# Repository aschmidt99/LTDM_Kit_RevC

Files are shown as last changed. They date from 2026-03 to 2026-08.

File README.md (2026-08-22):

# LTDM Kit Rev C

Firmware and hardware assets for a Teensy 4.1 based LTDM (Lorentz Time-Domain Multiplex) kit.

### Programming
Iterate quickly on dsp and string behavior in `Code/LTDM_Kit/render.cpp`, leaving precise timing of sensing and actuating untouched by user.
### Interaction
Map hardware controls (buttons/sliders/pedals) to your algorithm through the UI layer.

## Project Structure

- `Code/LTDM_Kit`: Firmware running on Teensy 4.1
- `Code/Python`: capture, analysis, and Audacity automation scripts
- `Code/LTDM_Kit_Control.maxpat`: a maxpatch for overriding the LTDM Kit physical UI or running LTDM kit main board without UI.
- `Electronics`: KiCad project (schematic and pcb) for PCB design
- `CAD`: mechanical STEP/STL assets for enclosure

## Program and Upload
Firmware can be edited and uploaded to the teensy 4.1 via the Arduino 2.X IDE or from VS code.

### Arduino IDE
To use the Arduino IDE, you will need to [(install the Arduino IDE)](https://support.arduino.cc/hc/en-us/articles/360019833020-Download-and-install-Arduino-IDE). Once installed, download the Teensy Board library by following the instructions [(here)](https://www.pjrc.com/teensy/td_download.html).

After firmware changes are made, make sure the teensy is connected and seen by the dropdown menu in the upper left of the IDE. Use the 'upload' button next to this to flash new firmware.

### Arduino CLI (direct)
If this is your first time connecting from a new machine, run this one-time setup first:

1. Install Arduino CLI.
2. Add the Teensy board index URL.
3. Update board indexes and install the Teensy core.
4. Plug in Teensy 4.1 with a data-capable USB cable.
5. Verify the detected USB port before upload.

Example one-time setup commands:

```bash
# Add PJRC Teensy package index (safe to run again if already present)
arduino-cli config add board_manager.additional_urls https://www.pjrc.com/teensy/package_teensy_index.json

# Refresh indexes and install Teensy core
arduino-cli core update-index
arduino-cli core install teensy:avr

# Confirm Teensy core is installed
arduino-cli core list
```

Check that your Teensy is visible and note its port:

```bash
arduino-cli board list
```

On macOS, Teensy ports commonly look like `/dev/cu.usbmodem*`.

To flash code directly from terminal:

```bash
cd Code/LTDM_Kit
arduino-cli compile --fqbn teensy:avr:teensy41 .
arduino-cli upload --fqbn teensy:avr:teensy41 -p /dev/cu.usbmodemXXXX .
```

### VS Code tasks
To flash firmware from VS code, you can use the premade VS code tasks by using `Cmd+Shift+P` -> `Tasks: Run Task` and select:

- `Teensy: Compile LTDM_Kit`
- `Teensy: Upload LTDM_Kit (prompt port)`
- `Teensy: Upload LTDM_Kit (auto port)`
- `Teensy: Compile + Upload LTDM_Kit (auto port)`

Task definitions live in `.vscode/tasks.json`.

## How the Firmware is Organized

### Essential core files (base firmware)

- `LTDM_Kit.ino`: startup order and top-level loop (`setup()` and `loop()`).
- `flexpwm.cpp` / `flexpwm.h`: hardware timing, ISR, ADC reads, and PWM update path.
- `render.cpp` / `render.h`: per-sample behavior, where algorithm/control logic is authored.
- `ui.cpp` / `ui.h`: physical control scan (buttons/sliders/pedals), LED updates, and serial telemetry printout.
- `channel.h`: per-channel runtime/state struct fields used by ISR and render.
- `context.h`: shared frame context passed into `render()` each sample.
- `pinmap.h`: board pin assignments and hardware routing constants.
- `system_config.h`: global compile-time configuration (sample rate, buffer sizes, PWM resolution).

### Optional or bonus helper modules

These are useful, but not strictly required for a minimal "sense -> render -> actuate" base path.

- `serialctrl.cpp` / `serialctrl.h`: optional host serial override of hardware UI state (used by Max patch control).
- `capture_stream.cpp` / `capture_stream.h`: optional deterministic capture trigger and streaming for measurement scripts.
- `harmonics.cpp` / `harmonics.h`: additive harmonic oscillator bank and zero-crossing pitch tracking.
- `visualAlias.cpp` / `visualAlias.h`: optional visual alias output behavior by plugging a 12V LED strip into one of the channels.
- `SineTable.cpp` / `SineTable.h`: lookup-table sine source used by harmonic/visual helper DSP.
- `debug.h`: compile-time debug print macros (`DEBUG_PRINT`, `DEBUG_PRINTLN`).

At runtime, the flow is:

1. ISR acquires channel state and UI state into `context`.
2. `render(context)` computes output values once per sample.
3. PWM/sense outputs are driven from those computed values.

## Codebase division-of-labor

This codebase intentionally separates three concerns:

1. Real-time infrastructure: sample timing, GPIO/PWM scheduling, ADC/sense capture.
2. Control surface: what knobs/buttons/pedals currently mean.
3. Algorithm: how measured input becomes actuation output.

The design goal is to let you iterate and develop actuation and feedback behavior without destabilizing anything with critical timing, such as the regular periodic sense + actuate loop.

In practice, treat `render.cpp` as your sandbox for algorithmic ideas:

- Feedback shaping
- Noise injection and excitation strategies
- RMS/energy targeting
- Harmonic synthesis
- Cross-channel coupling experiments

## Where to Make Changes

### Audio/actuation behavior

Edit `Code/LTDM_Kit/render.cpp`.

Key entry points:

- `bool renderSetup(LorentzContext *context)` for one-time setup
- `void render(LorentzContext *context)` for per-sample behavior

Useful signals available from `context`:

- `context->ch[0].in`, `context->ch[1].in` (channel's sensed audio input)
- `context->buttons[0]` (button 0-7 are the latching buttons, and 6-15 are the momentary push buttons)
- `context->sliders[0..15]` (slider 0-7 are the potentiometers, 8-15 are the sliders)
- `context->pedals[0..1]` (optionally connect up to 2 expression pedals)

### Button/slider behavior mapping

Edit `Code/LTDM_Kit/ui.cpp` and `Code/LTDM_Kit/render.cpp` together.

How it works:

1. `ui.cpp` scans physical mux inputs and sets UI LED outputs.
2. `render.cpp` assigns meaning to those logical indices.

### Pin assignments

Edit `Code/LTDM_Kit/pinmap.h` only if attaching additional functions to the available GPIOs.

### Render/control behavior (channel 1 focused)

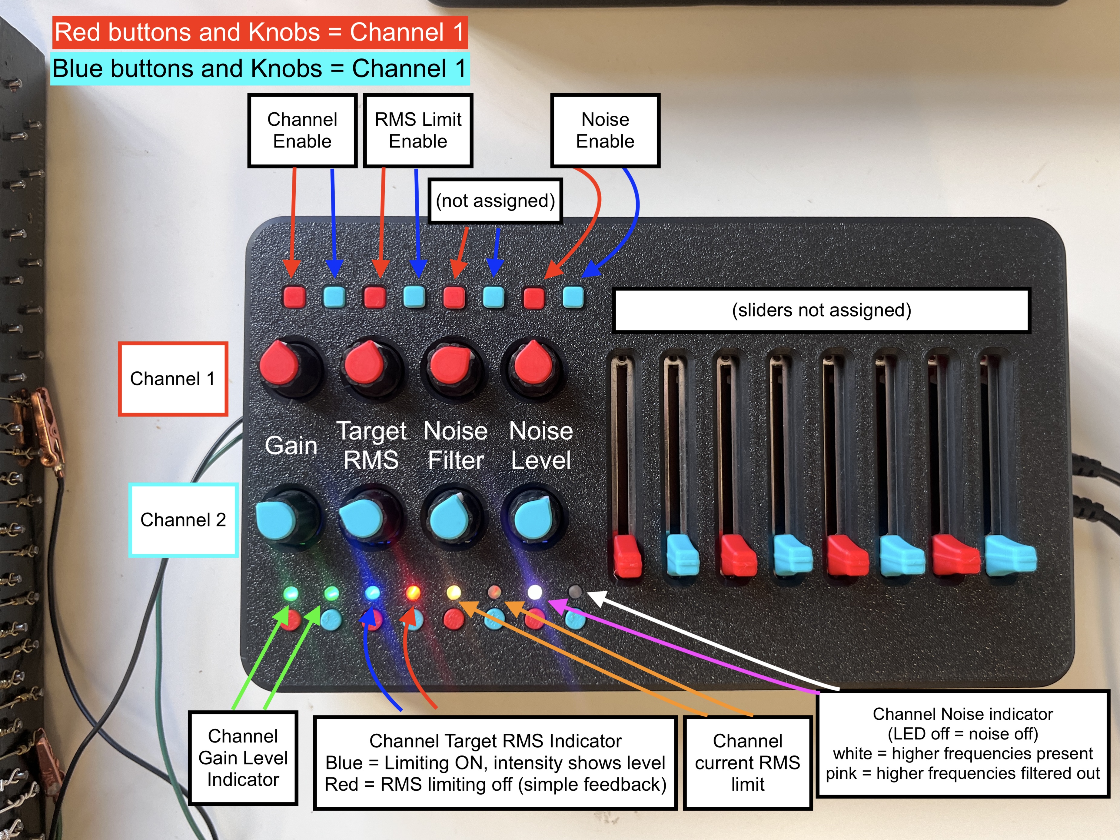
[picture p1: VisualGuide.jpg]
VisualGuide


In `Code/LTDM_Kit/render.cpp`:

- Button 0/1 enables channel 1 and 2 output respectively (`enablePin` high/low).
- Button 2 toggles RMS-targeted gain behavior for CH1.
- Button 6 gates CH1 noise injection.
- Button 8 requests capture start while capture is armed.

- Slider 0: CH1 feedback gain (`fbGain`).
- Slider 1: CH1 target RMS.
- Slider 2: noise update rate (acts like coarse smoothing on random term).
- Slider 3: CH1 noise scale.
- Slider 4: harmonic frequency smoothing parameter (`alpha`).
- Sliders 8..15: gains for harmonics 1..8 (`NUM_HARMONICS = 8`).

- Note: Channel 2 currently carries visual-alias pulse output behavior (`renderLEDPulse(...)`) rather than string feedback behavior

### LED/UI feedback

In `Code/LTDM_Kit/ui.cpp`:

- TLC5947 LEDs reflect enable/limit/target and measured RMS states.
- UI scan runs in two-step mux read/write cycles.
- `output()` also prints debug telemetry over serial every ~100 ms (as long as the the python audio capture stream is idle.)

### Serial override mode

`Code/LTDM_Kit/serialctrl.cpp` can override hardware controls via framed serial packets. There is an example max/msp patch ('LTDM_Kit_Control.maxpat') that already has this setup.

- Start marker: `255`
- End marker: `254`
- Payload: mode + 16 sliders + 16 buttons + 2 pedals (34 bytes)

When override is active, incoming values are written directly into the shared UI state arrays.

## Python Tools

The Python tools in `Code/Python` are used for measurement, capture automation, and analysis around the firmware:

- `capture_teensy_plus_interface.py`: Capture audio directly from Teensy (what the teensy 'hears' from the EMF sensing circuitry) and 2 channels of audio from a connected audio interface. Optionally import these files directly to audacity.
- `run_trial.py`: Prompt for trial/profile/duration and launch the capture workflow via named profiles.
- `capture_teensy_stream.py`: Capture Teensy stream only (without interface capture), with optional WAV export.
- `rigol_capture.py`: Run Rigol DS1054Z waveform/screenshot capture and write trial metadata.
- `load_rigol_capture.py`: Load and interactively inspect saved Rigol capture files.
- `rigol_screen.py`: Capture or convert Rigol's screen images.
- `plot_teensy_stream.py`: Plot saved Teensy stream files for quick signal inspection.

If you are starting from scratch, run this script first:

- `Code/Python/run_trial.py`

It prompts for trial and duration, auto-suggests the next trial number, and launches the full capture pipeline with known-good defaults.

Full Python docs:

- `Code/Python/PYTHON_README.md`

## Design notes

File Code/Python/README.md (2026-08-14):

# LTDM Python Scripts
# warning: I vibe-coded the hell out of this shit big time.

This folder contains two main workflows:

- LTDM Teensy + audio-interface capture, with optional Audacity timeline automation.
- Rigol DS1054Z waveform/screenshot capture and review.

## Folder Highlights

- `capture_teensy_plus_interface.py`: primary capture pipeline (Teensy + interface + Audacity import).
- `run_capture_trial_prompt.py`: interactive launcher that prompts trial and duration.
- `capture_teensy_stream.py`: Teensy-only binary/WAV capture.
- `legacy/capture_teensy_to_audacity.py`: older Teensy + Audacity flow (kept for reference/troubleshooting).
- `rigol_capture.py`: full 4-channel DS1054Z RAW capture to HDF5 + PNG + metadata.
- `load_rigol_capture.py`: browse and plot saved Rigol captures.
- `rigol_screen.py`: capture scope screen PNG or convert saved raw screen bytes.
- `plot_teensy_stream.py`: quick matplotlib plot of Teensy `.bin` streams.
- `rigol_common.py`: shared Rigol constants/helpers/plot logic.
- `legacy/test.py`: utility script for inspecting raw Rigol screen `.bin` files.

## Workflow Diagram

```mermaid
flowchart TD
  T[VS Code Task:\nPython Capture Teensy+Interface] --> P[run_capture_trial_prompt.py]
  P --> CPI[capture_teensy_plus_interface.py]
  CPI --> TS[(Teensy Serial Stream)]
  CPI --> IF[(Audio Interface Capture)]
  CPI --> AU[(Audacity import/update optional)]
  CPI --> EXP[(experiments/ output)]

  U1[Manual run] --> CTS[capture_teensy_stream.py]
  CTS --> EXP

  U2[Manual run] --> RIG[rigol_capture.py]
  RIG --> RC[rigol_common.py]
  RIG --> RS[rigol_screen.py]
  RIG --> EXP

  U3[Manual run] --> LRC[load_rigol_capture.py]
  LRC --> RC
  LRC --> EXP

  LEG[legacy/] --> LTA[legacy/capture_teensy_to_audacity.py]
  LEG --> TST[legacy/test.py]
```

## Requirements

Use Python 3.10+ recommended.

Install core dependencies:

```bash
python3 -m pip install pyserial numpy sounddevice soundfile matplotlib h5py ds1054z python-vxi11 pillow questionary
```

Notes:
- On macOS, `sounddevice` requires microphone permissions for terminal/VS Code.
- Audacity automation requires mod-script-pipe enabled and Audacity running.

## Recommended Daily Workflow (LTDM Capture)

### Option A: VS Code task (recommended)

Run task:

- `Python: Capture Teensy+Interface (prompt trial/duration)`

This task runs `run_capture_trial_prompt.py`, which:

- Suggests next trial number from `experiments/TeensyCapture/audacity_timeline_state.json`.
- Lets you override trial (including rerun of an existing trial).
- Prompts duration in seconds.
- Launches `capture_teensy_plus_interface.py` with project defaults.

### Option B: direct command

```bash
cd Code/Python
python3 capture_teensy_plus_interface.py \
  --port /dev/cu.usbmodem199934501 \
  --trial 7 \
  --duration 3 \
  --iface-device 6 \
  --iface-sample-rate 192000 \
  --iface-channels 2 \
  --iface-start-mode arm-gated \
  --iface-pre-roll 0.05 \
  --iface-post-roll 0.05 \
  --iface-trim-to-teensy \
  --iface-auto-align \
  --audacity-import \
  --audacity-command-spacing 0.25 \
  --audacity-reset-passes 3 \
  --audacity-pre-import-delay 0.10 \
  --audacity-post-import-delay 0.10
```

## Script Reference

## 1) `capture_teensy_plus_interface.py`

Primary synchronized capture script.

What it does:
- Arms Teensy and captures serial stream (2ch, 20 kHz).
- Captures interface audio (multi-channel, typically 2ch at 192 kHz).
- Optionally auto-aligns interface to Teensy via envelope correlation.
- Optionally trims interface exactly to Teensy duration.
- Writes per-trial WAVs + metadata JSON.
- Optionally imports/appends clips to 4 fixed Audacity tracks.

Key outputs per trial:
- `teensy_stream.bin`
- `teensy_stream_Ch1.wav`
- `teensy_stream_ch2.wav`
- `interface_capture_ch1.wav`
- `interface_capture_ch2.wav`
- `teensy_interface_capture_metadata.json`

Useful flags:
- `--iface-list-devices`
- `--iface-start-mode marker|arm|arm-gated`
- `--iface-auto-align` / `--iface-no-auto-align`
- `--iface-trim-to-teensy` / `--iface-no-trim-to-teensy`
- `--audacity-import` / `--no-audacity-import`
- `--audacity-reset-timeline`

## 2) `run_capture_trial_prompt.py`

Interactive launcher for the main capture script.

What it does:
- Reads prior timeline state.
- Proposes auto-incremented trial.
- Prompts trial + duration in terminal.
- Runs the full capture command with known-good defaults.

Run:

```bash
cd Code/Python
python3 run_capture_trial_prompt.py
```

## 3) `capture_teensy_stream.py`

Teensy-only capture utility.

What it does:
- Arms Teensy and waits for capture marker.
- Captures binary stream for requested duration.
- Saves raw channel splits and optional WAVs.

Run example:

```bash
cd Code/Python
python3 capture_teensy_stream.py \
  --port /dev/cu.usbmodem199934501 \
  --trial 1 \
  --duration 5 \
  --save-wav
```

## 4) `legacy/capture_teensy_to_audacity.py`

Legacy Audacity automation script.

Use this mainly for regression/troubleshooting versus the newer pipeline.

Run example:

```bash
cd Code/Python
python3 legacy/capture_teensy_to_audacity.py --port /dev/cu.usbmodem199934501
```

## 5) `plot_teensy_stream.py`

Quick waveform viewer for Teensy `.bin` captures.

Run example:

```bash
cd Code/Python
python3 plot_teensy_stream.py experiments/TeensyCapture/trial_1/teensy_stream.bin --duration 1.0 --channel 1
```

## 6) `rigol_capture.py`

Interactive DS1054Z RAW waveform capture.

What it does:
- Connects to Rigol via LAN/VXI-11 using `SCOPE_IP` from `rigol_common.py`.
- Captures scope screen.
- Stops scope if needed.
- Reads 6M-point RAW data for all 4 channels.
- Saves HDF5 + trial metadata + rendered PNG.

Run:

```bash
cd Code/Python
python3 rigol_capture.py
```

## 7) `load_rigol_capture.py`

Interactive loader/viewer for prior Rigol captures.

Run:

```bash
cd Code/Python
python3 load_rigol_capture.py
```

## 8) `rigol_screen.py`

Screen capture/conversion helper.

Live capture:

```bash
cd Code/Python
python3 rigol_screen.py --ip 169.254.123.183 --out rigol_screen.png
```

Convert existing raw screen file:

```bash
cd Code/Python
python3 rigol_screen.py --bin 20260811_rigol_screen.bin
```

## 9) `rigol_common.py`

Shared module used by Rigol scripts.

Contains:
- `SCOPE_IP`
- Channel mappings/colors
- RAW count to voltage conversion
- Scope-style plotting + zoom/decimation behavior

## 10) `legacy/test.py`

Small diagnostic utility for raw scope screen bytes.

Use when debugging corrupted/partial `.bin` screen captures.

Run:

```bash
cd Code/Python
python3 legacy/test.py
```

## Data Layout

Typical output tree:

```text
Code/Python/experiments/
  TeensyCapture/
    audacity_timeline_state.json
    trial_1/
    trial_2/
  <RigolExperimentName>/
    experiment.json
    trial_1/
      rigol_capture.h5
      rigol_capture.png
      rigol_screen.png
      trial_metadata.json
```

## Troubleshooting

Audacity import does not work:
- Confirm Audacity is open.
- Confirm mod-script-pipe is enabled.
- Confirm pipe files exist at `/tmp/audacity_script_pipe.to.<uid>` and `/tmp/audacity_script_pipe.from.<uid>`.

No interface input:
- Run `capture_teensy_plus_interface.py --iface-list-devices`.
- Verify `--iface-device` index/name.
- Check macOS microphone permissions.

Rigol connection fails:
- Verify scope IP in `rigol_common.py`.
- Confirm LAN link and that scope responds on VXI-11.

## Quick Sanity Checks

Compile scripts:

```bash
cd Code/Python
python3 -m py_compile capture_teensy_plus_interface.py run_capture_trial_prompt.py
```

Run one prompted trial:

```bash
cd Code/Python
python3 run_capture_trial_prompt.py
```

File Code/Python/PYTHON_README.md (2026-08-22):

# LTDM Python Scripts
## Warning: I vibe-coded the hell out of this shit big time.
This folder contains two main workflows:

- LTDM Teensy + audio-interface capture, with optional Audacity timeline automation.
- Rigol DS1054Z data capture and review.

## Quick Start

Run an interactive trial:

```bash
cd Code/Python
python3 run_trial.py
```

Run a non-interactive trial:

```bash
cd Code/Python
python3 run_trial.py --experiment TeensyCapture --trial 1 --profile teensy_interface_no_audacity --duration 5
```

Run Teensy-only capture:

```bash
cd Code/Python
python3 -m capture.teensy_stream --port /dev/cu.usbmodem199934501 --trial 1 --duration 5 --save-wav
```

## Folder Map

- `capture/`: Teensy and interface capture implementations.
- `rigol/`: Rigol capture, scope screen, and shared Rigol plotting helpers.
- `core/`: Shared path, profile, and metadata normalisation helpers.
- `analysis/`: Post-capture plotting/inspection tools.
- `docs/`: Python-side technical schema/reference docs.
- `run_trial.py` remains the top-level interactive launcher.

## Metadata Schema

Schema design is fixed in:

- `docs/trial_metadata_schema_v2.md`

This schema is the canonical contract for trial metadata before true acquisition begins.
It defines:

- Required versus optional fields.
- Authority precedence (firmware > measured properties > Python defaults).
- Trial failure semantics.
- Relative-path policy.
- Audacity lifecycle event recording.
- Assignment map policy (including explicit `N/A` for unassigned controls).
- Required FlexPWM TDM timing metadata using meaningful labels (for example sample period, main sense pulse end, alt sense pulse start/end, actuation pulse start) with time and duty-cycle values.

Telemetry integration reads firmware `@TLM1` arm snapshots before capture marker bytes and stores the payload in trial metadata.

Ingestion/persistence writes canonical schema metadata to:

- `trials/trial_####/trial_metadata_v2.json`

Capture scripts still write their existing operational metadata files, but canonical firmware authority, FlexPWM timing, controls, stream status, and relative-path file manifests now live in `trial_metadata_v2.json`.
Operational metadata includes a `schema_v2_path` pointer so downstream tooling can resolve the canonical record directly.

Audacity lifecycle automation records concise `lifecycle_events` with UTC timestamps (launch/open-or-create/import/save/close/error) and persists Audacity status into both operational metadata and schema-v2 metadata.
For each experiment, automation uses `orchestration/<experiment_name>.aup3`: it opens this project when needed, or creates it on first save without issuing an explicit Audacity New command.
Follow-up trials default to append mode and skip explicit project reopening to avoid "already open in another window" errors; rebuild mode is only forced when track count is successfully queried and is below the required base tracks.
If Audacity is not running, automation fails fast with a recorded lifecycle error rather than hanging on script-pipe open.
To reduce post-import/save instability, additional padding is available with `--audacity-pre-save-delay` and `--audacity-post-save-delay`.
When using `run_trial.py`, these delay flags are forwarded automatically to `capture.teensy_plus_interface`.

Repository hygiene and workflow stability includes two safeguards:

- `run_trial.py` resolves script/output paths from its own file location, so it behaves consistently regardless of current working directory.
- `.gitignore` excludes generated artefacts (`.DS_Store`, `__pycache__`, `.pyc`, trial outputs, and local Audacity project sidecars).

## Folder Highlights

- `capture/teensy_plus_interface.py`: primary capture pipeline (Teensy + interface + Audacity import).
- `run_trial.py`: interactive trial runner using named capture profiles.
- `capture/teensy_stream.py`: Teensy-only binary/WAV capture.
- `rigol/capture.py`: full 4-channel DS1054Z RAW capture to HDF5 + PNG + metadata.
- `rigol/load_capture.py`: browse and plot saved Rigol captures.
- `core/experiment_profile.py`: shared experiment-level metadata loader/prompt/save helper.
- `rigol/screen.py`: capture scope screen PNG or convert saved raw screen bytes.
- `analysis/plot_teensy_stream.py`: quick matplotlib plot of Teensy `.bin` streams.
- `rigol/common.py`: shared Rigol constants/helpers/plot logic.

## Workflow Diagram

```mermaid
flowchart TD
  T[VS Code Task:\nPython Capture Teensy+Interface] --> P[run_trial.py]
  P --> CPI[capture.teensy_plus_interface]
  CPI --> TS[(Teensy Serial Stream)]
  CPI --> IF[(Audio Interface Capture)]
  CPI --> AU[(Audacity import/update optional)]
  CPI --> EXP[(experiments/ output)]

  U1[Manual run] --> CTS[capture.teensy_stream]
  CTS --> EXP

  U2[Manual run] --> RIG[rigol.capture]
  RIG --> RC[rigol.common]
  RIG --> RS[rigol.screen]
  RIG --> EXP

  U3[Manual run] --> LRC[rigol.load_capture]
  LRC --> RC
  LRC --> EXP
```

## Requirements

Use Python 3.10+ recommended.

Install core dependencies:

```bash
python3 -m pip install pyserial numpy sounddevice soundfile matplotlib h5py ds1054z python-vxi11 pillow questionary
```

Notes:
- On macOS, `sounddevice` requires microphone permissions for terminal/VS Code.
- Audacity automation requires mod-script-pipe enabled and Audacity running.

### macOS Apple Silicon note (important)

If you see an error like "incompatible architecture (have 'x86_64', need 'arm64')" when importing `matplotlib`, you are launching the script with the wrong Python interpreter.

For this repo, use the project virtual environment interpreter directly:

```bash
cd Code/Python
../../.venv/bin/python -m rigol.capture
```

If needed, reinstall the plotting stack into that same interpreter:

```bash
../../.venv/bin/python -m pip install --upgrade --force-reinstall matplotlib numpy
```

## Recommended Daily Workflow (LTDM Capture)

### Option A: VS Code task (recommended)

Run task:

- `Python: Capture Teensy+Interface (prompt trial/duration)`

This task runs `run_trial.py`, which:

- Prompts experiment name (default `TeensyCapture`) when not passed by flag.
- Suggests next trial number from `experiments/TeensyCapture/orchestration/audacity_timeline_state.json` (with folder fallback).
- Lets you override trial (including rerun of an existing trial).
- Prompts for one profile: `interface_audacity`, `interface_no_audacity`, `teensy_interface_audacity`, `teensy_interface_no_audacity`, `rigol_only`, `full_stack_audacity`, or `full_stack_no_audacity`.
- Uses duration from `orchestration/experiment_profile.json` (`duration_seconds`) for non-`rigol_only` profiles.
- Accepts `--duration` as an override for a specific run.
- For trial 2+, shows “Change user-reported variable?” with an arrow-navigable field list (current values shown) and saves any edits before capture.
- Prompts once for experiment metadata if `orchestration/experiment_profile.json` does not yet exist.
- Launches `capture.teensy_plus_interface` with project defaults.

### Capture Profiles

- `interface_audacity`: Interface recording only, with Audacity import.
- `interface_no_audacity`: Interface recording only, without Audacity import.
- `rigol_only`: Rigol capture only for the selected experiment/trial.
- `teensy_interface_audacity`: Teensy + interface recording, with Audacity import.
- `teensy_interface_no_audacity`: Teensy + interface recording, without Audacity import.
- `full_stack_audacity`: Teensy + interface + Audacity + Rigol.
- `full_stack_no_audacity`: Teensy + interface + Rigol, without Audacity import.

### Option B: direct command

```bash
cd Code/Python
python3 -m capture.teensy_plus_interface \
  --port /dev/cu.usbmodem199934501 \
  --trial 7 \
  --duration 3 \
  --iface-device 6 \
  --iface-sample-rate 192000 \
  --iface-channels 2 \
  --iface-start-mode arm-gated \
  --iface-pre-roll 0.05 \
  --iface-post-roll 0.05 \
  --iface-trim-to-teensy \
  --iface-auto-align \
  --audacity-import \
  --audacity-command-spacing 0.25 \
  --audacity-reset-passes 3 \
  --audacity-pre-import-delay 0.10 \
  --audacity-post-import-delay 0.10
```

Audio + Rigol in one run:

```bash
cd Code/Python
python3 -m capture.teensy_plus_interface \
  --port /dev/cu.usbmodem199934501 \
  --trial 7 \
  --duration 3 \
  --iface-device 6 \
  --iface-sample-rate 192000 \
  --iface-channels 2 \
  --iface-start-mode arm-gated \
  --iface-pre-roll 0.05 \
  --iface-post-roll 0.05 \
  --iface-trim-to-teensy \
  --iface-auto-align \
  --audacity-import \
  --post-rigol
```

## Script Reference

1. `run_trial.py`
Purpose: interactive daily launcher (experiment/trial/profile prompts, duration defaults, metadata edits for follow-up trials).
Run:

```bash
cd Code/Python
python3 run_trial.py
```

2. `capture/teensy_plus_interface.py`
Purpose: main synchronized capture path (Teensy + interface + optional Audacity + optional post-Rigol).
Run:

```bash
cd Code/Python
python3 -m capture.teensy_plus_interface --help
```

Key flags: `--iface-list-devices`, `--iface-start-mode`, `--iface-auto-align`, `--iface-trim-to-teensy`, `--audacity-import`, `--audacity-reset-timeline`, `--post-rigol`, `--debug`.

3. `capture/teensy_stream.py`
Purpose: Teensy-only capture, with optional WAV output.
Run:

```bash
cd Code/Python
python3 -m capture.teensy_stream --port /dev/cu.usbmodem199934501 --trial 1 --duration 5 --save-wav
```

4. `analysis/plot_teensy_stream.py`
Purpose: quick viewer for Teensy `.bin` streams.
Run:

```bash
cd Code/Python
python3 -m analysis.plot_teensy_stream experiments/TeensyCapture/trials/trial_0001/macro_audio/teensy_stream.bin --duration 1.0 --channel 1
```

5. `rigol/capture.py`
Purpose: DS1054Z RAW capture (HDF5 + PNG + scope metadata) attached to experiment/trial.
Run:

```bash
cd Code/Python
python3 -m rigol.capture
python3 -m rigol.capture --experiment MyFirstExperiment --trial 1
```

6. `rigol/load_capture.py`
Purpose: interactive loader/plotter for previous Rigol captures.
Run:

```bash
cd Code/Python
python3 -m rigol.load_capture
```

7. `rigol/screen.py`
Purpose: scope screen capture and `.bin` to `.png` conversion.
Run:

```bash
cd Code/Python
python3 -m rigol.screen --ip 169.254.123.183 --out rigol_screen.png
python3 -m rigol.screen --bin 20260811_rigol_screen.bin
```

8. `rigol/common.py` (internal shared module)
Purpose: `SCOPE_IP`, channel labels/colours, conversion helpers, and scope-style plotting utilities used by Rigol tools.

Primary per-trial outputs from the main capture path:
- `trials/trial_####/macro_audio/teensy_stream.bin`
- `trials/trial_####/macro_audio/teensy_stream_Ch1.wav`
- `trials/trial_####/macro_audio/teensy_stream_ch2.wav`
- `trials/trial_####/macro_audio/interface_capture_ch1.wav`
- `trials/trial_####/macro_audio/interface_capture_ch2.wav`
- `trials/trial_####/trial_audio_capture_metadata.json`
- `trials/trial_####/trial_metadata_v2.json`
- `trials/trial_####/trial_manifest.json`

## Data Layout

Typical output tree:

```text
Code/Python/experiments/
  TeensyCapture/
    orchestration/
      experiment_profile.json
      audacity_timeline_state.json
    trials/
      trial_0001/
        trial_manifest.json
        trial_audio_capture_metadata.json
        macro_audio/
          teensy_stream.bin
          teensy_stream_Ch1.wav
          teensy_stream_ch2.wav
          interface_capture_ch1.wav
          interface_capture_ch2.wav
        micro_scope/
          capture_001/
            rigol_capture.h5
            rigol_capture.png
            rigol_screen.png
            scope_capture_meta.json
  <OtherExperimentName>/
    orchestration/
      experiment_profile.json
    trials/
      ...
```

## Troubleshooting

Audacity import does not work:
- Open Audacity first, enable mod-script-pipe, then verify both pipes exist: `/tmp/audacity_script_pipe.to.<uid>` and `/tmp/audacity_script_pipe.from.<uid>`.

No interface input:
- List devices with `python3 -m capture.teensy_plus_interface --iface-list-devices`, then set `--iface-device` and check macOS microphone permissions.

Rigol connection fails:
- Confirm `SCOPE_IP` in `rigol/common.py`, verify LAN link, and confirm the scope is reachable on VXI-11.

## Quick Sanity Checks

Compile scripts:

```bash
cd Code/Python
python3 -m py_compile run_trial.py capture/teensy_plus_interface.py capture/teensy_stream.py rigol/capture.py rigol/load_capture.py rigol/common.py rigol/screen.py core/experiment_profile.py core/path_layout.py core/trial_metadata.py analysis/plot_teensy_stream.py
```

Run one prompted trial:

```bash
cd Code/Python
python3 run_trial.py
```

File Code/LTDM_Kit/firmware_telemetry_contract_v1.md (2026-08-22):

# LTDM Firmware Telemetry Contract v1

Status: Phase 2 draft contract
Owner: LTDM firmware + Python capture integration
Last updated: 2026-08-22

## Goal
Define a stable telemetry contract from Teensy firmware to Python host so trial metadata can be populated from firmware authority, using meaningful labels rather than raw register names.

## Design Principles
- Preserve current capture behaviour and timing.
- Keep ARM/START workflow backward-compatible.
- Emit telemetry before binary stream starts.
- Use UTF-8 line-delimited JSON frames for easy parsing.
- Keep field names aligned with trial_metadata_schema_v2.md.

## Backward Compatibility
Existing protocol today:
- Host sends `A` + 1-byte duration seconds.
- Firmware responds with `ARMED\n`.
- On start trigger, firmware sends marker bytes `0xAA 0x55`.
- Firmware then streams binary int16 audio payload.

v1 telemetry keeps all of the above unchanged and adds framed telemetry lines after ARMED, before marker.

## Wire Format
Each telemetry frame is one UTF-8 line:
- Prefix: `@TLM1 `
- Payload: one compact JSON object
- Terminator: `\n`

Example line:
`@TLM1 {"message_type":"arm_snapshot","protocol_version":"1",...}\n`

Notes:
- Prefix prevents accidental collisions with debug text.
- JSON payload must be single-line.
- No telemetry frames are sent after marker `0xAA55`.

## Message Sequence
1. Host sends ARM command `A <duration_byte>`.
2. Firmware validates duration and arms capture.
3. Firmware sends `ARMED\n` (legacy ack).
4. Firmware sends one required telemetry frame (`arm_snapshot`).
5. Optionally firmware may send additional `@TLM1` frames for diagnostics.
6. User presses start trigger.
7. Firmware sends marker bytes `0xAA 0x55`.
8. Firmware streams binary capture data.

## Required Telemetry Message
`message_type = "arm_snapshot"`

Required top-level fields:
- message_type: string, fixed `arm_snapshot`
- protocol_version: string, fixed `1`
- firmware:
  - samplerate_hz: number
  - resolution_pwm_bits: number
  - max_duty_ch1: number
  - max_duty_ch2: number
- flexpwm_tdm_timing:
  - reference:
    - time_zero_symbol: string, fixed `FLEXPWM2_SM0VAL0`
    - time_zero_cycle: number
  - config_constants:
    - samplerate_hz: number
    - max_duty_ch1: number
    - max_duty_ch2: number
    - resolution_pwm_bits: number
  - derived:
    - val_input: number
    - period_cycles: number
    - period_us: number
    - cycles: number
    - cycles_formula: string
  - consistency_checks:
    - all_actuation_start_times_equal: boolean
  - timing_table:
    - array of rows:
      - label: string
      - cycle_value: number
      - duty_cycle: number
      - time_us: number
- controls:
  - raw_state:
    - buttons: bool[16]
    - sliders: number[16] in [0,1]
    - pedals: number[2] in [0,1]
  - assignment_map:
    - source: string enum (`firmware_reported` preferred)
    - version_tag: string
    - entries: object containing button_0..button_15, slider_0..slider_15, pedal_0..pedal_1
      - values are meaningful labels or `N/A`
  - interpreted_state:
    - channel_1 and channel_2 objects when available

## Required Timing Labels
`flexpwm_tdm_timing.timing_table` must include at least:
- `main_sense_pulse_end`
- `alt_sense_pulse_start`
- `alt_sense_pulse_end`
- `actuation_pulse_start`

## Conversion Rules
- `period_us = 1e6 / samplerate_hz`
- `duty_cycle = 100 * (cycle_value / period_cycles)`
- `time_us = (cycle_value - time_zero_cycle) * (period_us / period_cycles)`

## Current Firmware Mapping (for implementation)
From flexpwm.cpp:
- `period_cycles` comes from `FLEXPWM2_SM2VAL1 + 1`.
- `val_input` is the input to `setOutputPWM(val)`.
- `cycles` is computed as `((uint32_t)val * period_cycles) >> ResolutionPWM`.
- `main_sense_pulse_end` maps to `FLEXPWM2_SM1VAL3`.
- `alt_sense_pulse_start` maps to `FLEXPWM2_SM0VAL0`.
- `alt_sense_pulse_end` maps to `FLEXPWM2_SM0VAL3`.
- `actuation_pulse_start` maps to `FLEXPWM2_SM2VAL2`.
- Equality check compares `SM2VAL2`, `SM2VAL4`, `SM3VAL2`, and `SM3VAL4`.

## Host Parsing Requirements
- Keep existing `ARMED` and marker handling.
- After ARMED, accumulate and parse `@TLM1 ` lines until marker arrives.
- Ignore malformed telemetry frames, but continue capture.
- If no valid telemetry frame is parsed, set metadata `report_source` fallback appropriately.

## Failure Behaviour
- Telemetry frame parse failure alone does not abort capture.
- Missing required telemetry fields marks firmware telemetry status as failed for metadata.
- Trial may still complete with trial_status failed if required telemetry is missing by schema policy.

## Example Telemetry Frame
@TLM1 {"message_type":"arm_snapshot","protocol_version":"1","firmware":{"samplerate_hz":20000,"resolution_pwm_bits":12,"max_duty_ch1":0.35,"max_duty_ch2":1.0},"flexpwm_tdm_timing":{"reference":{"time_zero_symbol":"FLEXPWM2_SM0VAL0","time_zero_cycle":0},"config_constants":{"samplerate_hz":20000,"max_duty_ch1":0.35,"max_duty_ch2":1.0,"resolution_pwm_bits":12},"derived":{"val_input":340,"period_cycles":7500,"period_us":50.0,"cycles":622,"cycles_formula":"cycles = (val * period_cycles) >> resolution_pwm_bits"},"consistency_checks":{"all_actuation_start_times_equal":true},"timing_table":[{"label":"main_sense_pulse_end","cycle_value":933,"duty_cycle":12.44,"time_us":6.22},{"label":"alt_sense_pulse_start","cycle_value":0,"duty_cycle":0.0,"time_us":0.0},{"label":"alt_sense_pulse_end","cycle_value":1866,"duty_cycle":24.88,"time_us":12.44},{"label":"actuation_pulse_start","cycle_value":1555,"duty_cycle":20.73,"time_us":10.37}]},"controls":{"raw_state":{"buttons":[1,0,0,0,0,0,1,0,0,0,0,0,0,0,0,0],"sliders":[0.42,0.18,0.90,0.31,0.08,0.50,0.49,0.12,0,0,0,0,0,0,0,0],"pedals":[0.0,0.0]},"assignment_map":{"source":"firmware_reported","version_tag":"render_map_v1","entries":{"button_0":"channel_1.enable","button_1":"channel_2.enable","button_2":"channel_1.rms_limiting_enabled","button_6":"channel_1.noise_enable","button_8":"capture_start_trigger","button_9":"N/A"}}}}

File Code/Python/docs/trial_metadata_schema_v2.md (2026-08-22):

# LTDM Trial Metadata Schema v2

Status: Phase 1 complete (approved)
Owner: LTDM capture workflow
Last updated: 2026-08-21

## Purpose
This schema defines the canonical trial metadata contract for LTDM data acquisition.
It applies to:
- Teensy stream captures
- Interface captures
- Rigol captures
- Audacity timeline/project automation metadata

The schema is designed to be finalised before any true acquisition campaign starts.

## Core Decisions (locked)
- Trial identity is experiment_title + trial_number.
- No global trial_id is required.
- Firmware-reported values are the highest authority.
- Both UTC wall-clock timestamps and monotonic timing diagnostics are stored.
- Numeric values are stored as JSON numbers, not strings.
- Units are encoded in field names (for example, sample_rate_hz, magnet_distance_mm).
- All file paths are stored relative to experiment root.
- Partial captures are marked failed.
- Audacity project lifecycle events are included.
- Backward compatibility with old metadata keys is not required.
- All controls are recorded. If a control has no active assignment, use N/A in assignment_map.

## Value Authority Order
When multiple sources disagree, use this precedence:
1. firmware_reported
2. measured_file_properties
3. python_defaults

## Top-Level Object
Required top-level keys:
- schema_version
- experiment_title
- trial_number
- capture_profile
- trial_status
- capture_time_utc
- capture_time_local
- firmware
- flexpwm_tdm_timing
- controls
- streams
- files
- experiment_profile_snapshot

Optional top-level keys:
- timing
- audacity
- errors

## Field Specification

### 1) Identity and versioning
- schema_version: string, required, fixed value "2.0"
- experiment_title: string, required
- trial_number: integer >= 1, required
- capture_profile: string, required
- trial_status: string enum, required
  - allowed: success, failed
- capture_time_utc: string (ISO 8601 UTC), required
- capture_time_local: string (ISO 8601 with timezone offset), required

### 2) Timing
- timing: object, optional
- timing.monotonic: object, optional
  - t_arm_send_s: number, optional
  - t_armed_ack_s: number, optional
  - t_marker_s: number, optional
  - t_capture_done_s: number, optional
  - t_stop_cmd_s: number, optional
- timing.derived: object, optional
  - arm_ack_ms: number, optional
  - record_cmd_after_marker_ms: number, optional
  - teensy_capture_after_marker_s: number, optional
- timing.wall_clock: object, optional
  - capture_start_utc: string, optional
  - capture_end_utc: string, optional

### 3) Firmware authority block
- firmware: object, required
  - samplerate_hz: number, required
  - protocol_version: string, required
  - build_id: string, optional
  - git_commit: string, optional
  - board: string, optional
  - report_source: string enum, required
    - allowed: firmware, python_fallback
  - report_raw: object, optional

### 4) Controls block
- controls: object, required

- controls.raw_state: object, required
  - buttons: array[16] of boolean, required
  - sliders: array[16] of number in [0, 1], required
  - pedals: array[2] of number in [0, 1], optional

- controls.interpreted_state: object, optional
  - channel_1: object, optional
    - gain: number, optional
    - rms_limiting_enabled: boolean, optional
    - target_rms: number, optional
    - noise_level: number, optional
    - enabled: boolean, optional
  - channel_2: object, optional
    - gain: number, optional
    - rms_limiting_enabled: boolean, optional
    - target_rms: number, optional
    - noise_level: number, optional
    - enabled: boolean, optional
  - global_modes: object, optional

- controls.assignment_map: object, required
  - source: string enum, required
    - allowed: inferred_from_render, firmware_reported, manual
  - version_tag: string, required
  - entries: object, required
    - keys: button_0..button_15, slider_0..slider_15, pedal_0..pedal_1
    - values: string assignment label, or N/A

Assignment map policy:
- Uncertain or currently unassigned controls must be represented explicitly with N/A.
- Capture must not fail solely because mapping is uncertain.

### 4b) FlexPWM TDM timing block
- flexpwm_tdm_timing: object, required

- flexpwm_tdm_timing.reference: object, required
  - time_zero_symbol: string, required, fixed value FLEXPWM2_SM0VAL0
  - time_zero_cycle: number, required

- flexpwm_tdm_timing.config_constants: object, required
  - samplerate_hz: number, required
  - max_duty_ch1: number, required
  - max_duty_ch2: number, required
  - resolution_pwm_bits: number, required

- flexpwm_tdm_timing.derived: object, required
  - cycles: number, required
  - val_input: number, required
  - period_us: number, required
  - period_cycles: number, required
  - cycles_formula: string, required

- flexpwm_tdm_timing.consistency_checks: object, required
  - all_actuation_start_times_equal: boolean, required
  - note: string, optional

- flexpwm_tdm_timing.timing_table: array, required
  - each row is an object:
    - label: string, required
    - cycle_value: number, required
    - duty_cycle: number, required
    - time_us: number, required

Timing table policy:
- duty_cycle is normalised by sample period from SAMPLERATE.
- time_us is measured relative to FLEXPWM2_SM0VAL0.
- Include at least these rows:
  - main_sense_pulse_end
  - alt_sense_pulse_start
  - alt_sense_pulse_end
  - actuation_pulse_start

Recommended conversion formulas:
- period_us = 1e6 / samplerate_hz
- duty_cycle = 100 * (cycle_value / period_cycles)
- time_us = (cycle_value - FLEXPWM2_SM0VAL0) * (period_us / period_cycles)

Current firmware context (for implementation reference):
- SAMPLERATE, MaxDutyCh1, MaxDutyCh2 are defined in system_config.h.
- Cycles is derived in setOutputPWM() from ResolutionPWM and period cycles.
- FLEXPWM2_SM2VAL2/4 and FLEXPWM2_SM3VAL2/4 are currently initialised to the same rising-edge cycle.

Internal implementation mapping (not stored as metadata keys):
- main_sense_pulse_end := FLEXPWM2_SM1VAL3
- alt_sense_pulse_start := FLEXPWM2_SM0VAL0
- alt_sense_pulse_end := FLEXPWM2_SM0VAL3
- actuation_pulse_start := FLEXPWM2_SM2VAL2 (equivalent to SM2VAL4, SM3VAL2, SM3VAL4 in current setup)

### 5) Stream execution
- streams: object, required

- streams.teensy: object, required
  - requested: boolean, required
  - status: string enum, required
    - allowed: success, failed, skipped
  - sample_rate_hz: number, required when requested is true
  - channels: integer, required when requested is true

- streams.interface: object, required
  - requested: boolean, required
  - status: string enum, required
    - allowed: success, failed, skipped
  - sample_rate_hz: number, required when requested is true
  - channels: integer, required when requested is true

- streams.rigol: object, required
  - requested: boolean, required
  - status: string enum, required
    - allowed: success, failed, skipped
  - sample_rate_hz: number, optional
  - points_per_channel: integer, optional

Trial failure policy:
- If any requested stream has status failed, trial_status must be failed.

### 6) Files (relative paths only)
- files: object, required

- files.teensy: object, optional
  - raw_bin: string, optional
  - ch1_wav: string, optional
  - ch2_wav: string, optional

- files.interface: object, optional
  - ch1_wav: string, optional
  - ch2_wav: string, optional

- files.rigol: object, optional
  - hdf5: string, optional
  - png: string, optional
  - screen_png: string, optional
  - metadata_json: string, optional

- files.manifests: object, required
  - trial_manifest: string, required
  - trial_metadata: string, required

### 7) Audacity
- audacity: object, optional
  - enabled: boolean, required when audacity object exists
  - project: object, optional
    - path: string, optional (relative)
    - status: string enum, optional
      - allowed: created, opened, saved, failed
  - timeline_state_path: string, optional (relative)
  - lifecycle_events: array, optional
    - each event is an object:
      - ts_utc: string
      - event: string enum
        - allowed: launch_attempt, launch_success, open_project, create_project, import_tracks, save_project, close_project, error
      - details: object

### 8) Experiment snapshot
- experiment_profile_snapshot: object, required
- Numeric fields in this snapshot should be numbers where semantically numeric.

### 9) Errors
- errors: array, optional
- each item:
  - code: string, required
  - message: string, required
  - component: string enum, required
    - allowed: teensy, interface, rigol, audacity, orchestration

## Minimal Required Record Example
{
  "schema_version": "2.0",
  "experiment_title": "FinalForNow",
  "trial_number": 7,
  "capture_profile": "teensy_interface_no_audacity",
  "trial_status": "success",
  "capture_time_utc": "2026-08-21T15:30:00Z",
  "capture_time_local": "2026-08-21T16:30:00+01:00",
  "firmware": {
    "samplerate_hz": 20000,
    "protocol_version": "1",
    "report_source": "firmware"
  },
  "flexpwm_tdm_timing": {
    "reference": {
      "time_zero_symbol": "FLEXPWM2_SM0VAL0",
      "time_zero_cycle": 0
    },
    "config_constants": {
      "samplerate_hz": 20000,
      "max_duty_ch1": 0.35,
      "max_duty_ch2": 1.0,
      "resolution_pwm_bits": 12
    },
    "derived": {
      "cycles": 622,
      "val_input": 340,
      "period_us": 50.0,
      "period_cycles": 7500,
      "cycles_formula": "cycles = (val * (period_cycles + 1)) >> resolution_pwm_bits"
    },
    "consistency_checks": {
      "all_actuation_start_times_equal": true
    },
    "timing_table": [
      {"label": "main_sense_pulse_end", "cycle_value": 933, "duty_cycle": 12.44, "time_us": 6.22},
      {"label": "alt_sense_pulse_start", "cycle_value": 0, "duty_cycle": 0.0, "time_us": 0.0},
      {"label": "alt_sense_pulse_end", "cycle_value": 1866, "duty_cycle": 24.88, "time_us": 12.44},
      {"label": "actuation_pulse_start", "cycle_value": 1555, "duty_cycle": 20.73, "time_us": 10.37}
    ]
  },
  "controls": {
    "raw_state": {
      "buttons": [true, false, false, false, false, false, true, false, false, false, false, false, false, false, false, false],
      "sliders": [0.42, 0.18, 0.90, 0.31, 0.08, 0.50, 0.49, 0.12, 0.00, 0.00, 0.00, 0.00, 0.00, 0.00, 0.00, 0.00]
    },
    "assignment_map": {
      "source": "inferred_from_render",
      "version_tag": "render_map_v1",
      "entries": {
        "button_0": "channel_1.enable",
        "button_1": "channel_2.enable",
        "button_2": "channel_1.rms_limiting_enabled",
        "button_6": "channel_1.noise_enable",
        "button_8": "capture_start_trigger",
        "button_9": "N/A"
      }
    }
  },
  "streams": {
    "teensy": {"requested": true, "status": "success", "sample_rate_hz": 20000, "channels": 2},
    "interface": {"requested": true, "status": "success", "sample_rate_hz": 192000, "channels": 2},
    "rigol": {"requested": false, "status": "skipped"}
  },
  "files": {
    "teensy": {
      "raw_bin": "trials/trial_0007/macro_audio/teensy_stream.bin",
      "ch1_wav": "trials/trial_0007/macro_audio/teensy_stream_ch1.wav",
      "ch2_wav": "trials/trial_0007/macro_audio/teensy_stream_ch2.wav"
    },
    "manifests": {
      "trial_manifest": "trials/trial_0007/trial_manifest.json",
      "trial_metadata": "trials/trial_0007/trial_audio_capture_metadata.json"
    }
  },
  "experiment_profile_snapshot": {
    "operator": "adamschmidt"
  }
}

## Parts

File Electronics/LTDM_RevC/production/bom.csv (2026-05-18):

Designator | Footprint | Quantity | Value | LCSC Part #
C1, C3, C30, C34, C35, C36 | 0603 | 6 | 220pF
C11 | 0402 | 1 | 100n
C12, C13, C14, C15, C18, C19 | 0805 | 6 | 10u | C469541
C16 | 0402 | 1 | 1.2n
C2, C33 | C_Rect_L11.0mm_W5.1mm_P10.00mm_MKT | 2 | 10n | C183540
C22, C32 | CP_Radial_D10.0mm_P5.00mm | 2 | 1000u | C2960265
C23, C28 | 0402 | 2 | 100n | C162179
C24, C31 | 0805 | 2 | 10u 35v | C469541
C26, C29 | 0402 | 2 | 100n | C92753
C27, C5 | CP_Radial_D8.0mm_P3.50mm | 2 | 220u | C45072
C37, C38 | 0603 | 2 | 10n
C39, C40 | 0603 | 2 | 4.7n
C4 | CP_EIA-7343-31_Kemet-D | 1 | 100u | C189619
C41, C42, C43, C44, C45, C46, C48, C49 | 0603 | 8 | 10n | C3836718
C6, C7, C8, C9 | 0805 | 4 | 10u | C117956
CSR1, CSR2 | R_4527 | 2 | 0.1R 5W | C5127890
CU1, CU10, CU11, CU13, CU15, CU16, CU17, CU18, CU19, CU2, CU20, CU21, CU22, CU23, CU24, CU25, CU26, CU27, CU28, CU29, CU3, CU30, CU31, CU32, CU33, CU34, CU35, CU36, CU37, CU38, CU39, CU4, CU40, CU41, CU42, CU43, CU44, CU45, CU46, CU47, CU48, CU49, CU5, CU50, CU51, CU52, CU53, CU6, CU7, CU8, CU9 | 0603 | 51 | 100n
CU12, CU14 | 0805 | 2 | 1u | C24123
D1, D14, D15, D16, D17, D2, D7, D9 | D_SOD-123 | 8 | 1N4148W | C5345962
D3, D4, D8 | 0603 | 3 | LED | C79636
D5, D6 | SOT-23 | 2 | MMBZ5242BLT3G | C896784
J1, J10, J18, J19, J2, J20, J21, J23, J27, J29, J3, J30, J31, J32, J6, J8, J9 | PinHeader_1x03_P2.54mm_Vertical | 17 | Conn_01x03_Male | C2914353
J11, J14 | SolderJumper-2_P1.3mm_Open_Pad1.0x1.5mm | 2 | CSR_Bypass | C124375
J12, J15 | TerminalBlock_Spring_2_P5.08mm | 2 | SpringTerminal | C35616
J16, J22 | BarrelJack_Wuerth_6941xx301002 | 2 | Barrel_Jack | C3096082
J24, J28 | PinHeader_1x02_P2.54mm_Vertical | 2 | CSR_Bypass | C124375
J35, J36, J37, J38 | Jack_3.5mm_CUI_SJ1-3535NG_Horizontal | 4 | AudioJack3_SwitchTR | C4991610
J4 | PinHeader_2x05_P2.54mm_Vertical | 1 | Conn_02x05_Odd_Even | C376087
J5 | IDC-Header_2x15_P2.54mm_Vertical | 1 | Conn_02x15_Odd_Even | C358748
JP1, JP2, JP20, JP21 | SolderJumper-2_P1.3mm_Bridged_RoundedPad1.0x1.5mm | 4 | bridge
JP10, JP12, JP13, JP14, JP15, JP16, JP17, JP18, JP3, JP4, JP5, JP6, JP7, JP9 | SolderJumper-2_subtle | 14 | GND
L1 | L_Bourns_SRN6045TA | 1 | 3.3u | C3221229
PRC1, PRC2 | TerminalBlock_RND_205-00232_1x02_P5.08mm_Horizontal | 2 | Conn_01x02 | C430601
PWR_SW1 | SW_Slide_1P2T_CK_OS102011MS2Q | 1 | SW_SPST | C431547
Q1, Q3, Q5 | TO-220-3_Vertical | 3 | FQP27P06 | C7503194
Q15, Q16 | SOT-23 | 2 | BSS123 | C78962
Q2, Q4, Q6 | TO-220-3_Vertical | 3 | IRLZ44N | C22367197
R1, R115, R116, R12, R49, R59, R63, R8 | 0603 | 8 | 0
R10, R126, R127, R128, R129, R130, R131, R132, R133, R134, R135, R142, R143, R16, R22, R55, R61, R66, R74 | 0603 | 19 | 10k
R100, R124, R125, R137, R139, R15, R17, R21, R3, R33, R34, R35, R36, R42, R43, R44, R46, R5, R51, R53, R67, R70, R73, R92, R93, R95, R96, R97 | 0603 | 28 | 1k
R101, R98 | 0603 | 2 | 205 | C403059
R102, R99 | 0603 | 2 | 32.4 | C861326
R103, R104, R2, R41, R48, R50 | 0603 | 6 | 510 | C309660
R105, R106, R107, R108, R109, R110, R111, R112, R14, R19, R20, R4, R52, R65, R68, R69 | 0603 | 16 | 1.01k | C861188
R11, R18, R58, R71 | 0603 | 4 | 11 | C861645
R117, R136, R56, R72, R94 | 0603 | 5 | 2.2k
R118, R119, R120, R121 | 0402 | 4 | 787 | C728564
R122, R123 | 0603 | 2 | 392 | C861870
R13, R62 | 0603 | 2 | 20k
R138, R54, R6 | 0603 | 3 | 1Meg
R140, R141 | 0603 | 2 | 4.7k
R144 | 0402 | 1 | 176K | C862921
R23 | 0603 | 1 | 120
R26, R40 | 2512 | 2 | 100R 1W | C24920
R27, R29, R37, R38 | 0603 | 4 | 10
R28 | 0402 | 1 | 10R | C138066
R30 | 0402 | 1 | 20K
R31 | 0402 | 1 | 12K | C25752
R32 | 0402 | 1 | 2.2k
R45, R47 | 0402 | 2 | 12K 1% | C25535
R60, R76 | 0603 | 2 | 576 | C705869
R64, R77 | 0603 | 2 | 374 | C666871
R7 | 0603 | 1 | 100k
R90, R91 | 0603 | 2 | 47
RV1, RV10, RV7 | Potentiometer_Bourns_3314G_Vertical | 3 | 1k | C780221
SW1, SW2 | SW_Slide-SSSS918700 | 2 | SW_SP3T | C390919
SW3 | PinHeader_2x02_P2.54mm_Vertical | 1 | SW_DPST | C5272597
TP1, TP2 | TestPoint_THTPad_D2.0mm_Drill1.0mm | 2 | TP
TP10, TP11, TP12, TP13, TP14, TP15, TP16, TP17, TP19, TP21, TP39, TP40, TP41, TP42, TP43, TP44, TP45, TP46, TP47, TP48, TP6, TP9 | TestPoint_THTPad_D2.0mm_Drill1.0mm | 22 | TestPoint | C238122
TP18, TP20, TP22, TP23, TP26, TP27, TP28, TP29, TP30, TP49, TP5, TP7, TP8 | TestPoint_THTPad_D2.0mm_Drill1.0mm | 13 | TestPoint | C238127
TP24, TP4 | TestPoint_THTPad_D2.0mm_Drill1.0mm | 2 | RectOut | C238122
TP25, TP3, TP37, TP38 | TestPoint_THTPad_D2.0mm_Drill1.0mm | 4 | TestPoint
TP31, TP32 | TestPoint_THTPad_D2.0mm_Drill1.0mm | 2 | CGain_Out2 | C238122
TP33, TP34 | TestPoint_THTPad_D2.0mm_Drill1.0mm | 2 | CRect_Out1 | C238122
TP35, TP36 | TestPoint_THTPad_D2.0mm_Drill1.0mm | 2 | CClamp_Out1 | C238122
U1, U26, U31, U32 | SOT-23-6 | 4 | 74LVC1G11 | C22356918
U10 | SOIC-8-1EP_3.9x4.9mm_P1.27mm_EP2.95x4.9mm_Mask2.71x3.4mm_ThermalVias | 1 | AP64500SP | C2070920
U11 | SOP-8_3.76x4.96mm_P1.27mm | 1 | LM7332 | C97826
U12 | SOIC-8_3.9x4.9mm_P1.27mm | 1 | TC4427xOA | C636893
U13, U14, U18, U19, U22, U23, U24, U25, U27, U28, U30, U4, U6 | SOP-8_3.76x4.96mm_P1.27mm | 13 | OPA1612AxD | C94590
U15, U5 | SOP-8_3.76x4.96mm_P1.27mm | 2 | LM393 | C7955
U16, U2 | SOIC-14_3.9x8.7mm_P1.27mm | 2 | LF398_SOIC14 | C2864267
U17, U21, U29, U3 | SOP-8_3.76x4.96mm_P1.27mm | 4 | OPA2350 | C55904
U20 | VSSOP-8_2.3x2mm_P0.5mm | 1 | 74AUC2G86 | C2876515
U36 | VSSOP-8_2.3x2mm_P0.5mm | 1 | 74LVC2G74 | C7851
U7 | Teensy4.1A | 1 | Teensy4.1A | C41376163
U8 | Teensy4.1B | 1 | Teensy4.1B | C41376163
U9 | SOIC-8_3.9x4.9mm_P1.27mm | 1 | TC4426 | C148047

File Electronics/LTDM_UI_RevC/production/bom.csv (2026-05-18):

Designator | Footprint | Quantity | Value | LCSC Part #
C5 | CP_Radial_D8.0mm_P3.50mm | 1 | 220u | C45072
CU1, CU10, CU11, CU12, CU2, CU3, CU5, CU6, CU7, CU8, CU9 | 0603 | 11 | 100n
D1, D2, D3, D4, D5, D6, D7, D8 | 19237R6GHBHCA012T | 8 | LED_RGBA | C60105
D10, D9 | 0603 | 2 | LED | C79636
J21, J22 | Jack_6.35mm_Neutrik_NMJ6HCD2_Horizontal | 2 | NMJ6HCD2 | C368502
J24 | IDC-Header_2x15_P2.54mm_Vertical | 1 | Conn_02x15_Odd_Even | C358748
R1, R2, R23 | 0603 | 3 | 120
R24 | 0603 | 1 | 2.2k
R25, R26, R27, R28, R29, R30, R31, R32 | 0603 | 8 | 10k
R3, R4 | 0603 | 2 | 100
RV1, RV2 | Potentiometer_Bourns_PTV09A-1_Single_Vertical | 2 | 10k | C5357831
RV3, RV4, RV5, RV6, RV7, RV8 | Potentiometer_Bourns_PTV09A-1_Single_Vertical | 6 | 10k | C5357831
SW1, SW2, SW3, SW4, SW5, SW6, SW7, SW8 | SW_Push_1P1T_NO_Vertical_Wuerth_434133025816 | 8 | tactile | C5504987
SW10, SW11, SW12, SW13, SW14, SW15, SW16, SW9 | SW_Push_DPDT_PS-5850SVB-6PL | 8 | SW_Push_DPDT | C5155567
U1 | QFN-32-1EP_5x5mm_P0.5mm_EP3.45x3.45mm | 1 | TLC5947RHB | C181402
U2, U3 | SSOP-24_5.3x8.2mm_P0.65mm | 2 | CD74HC4067SM | C98457
VR1, VR2, VR3, VR4, VR5, VR6, VR7, VR8 | RS45111A900F | 8 | RS45111A900F | C470640

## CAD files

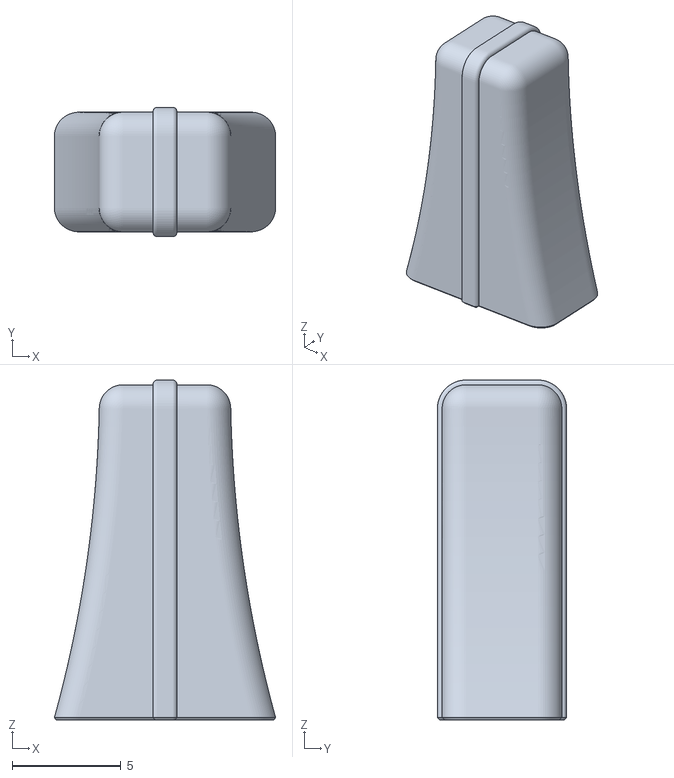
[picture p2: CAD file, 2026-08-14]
CAD/Enclosure/slider_cap.stl
10.2 x 5.94 x 15.6

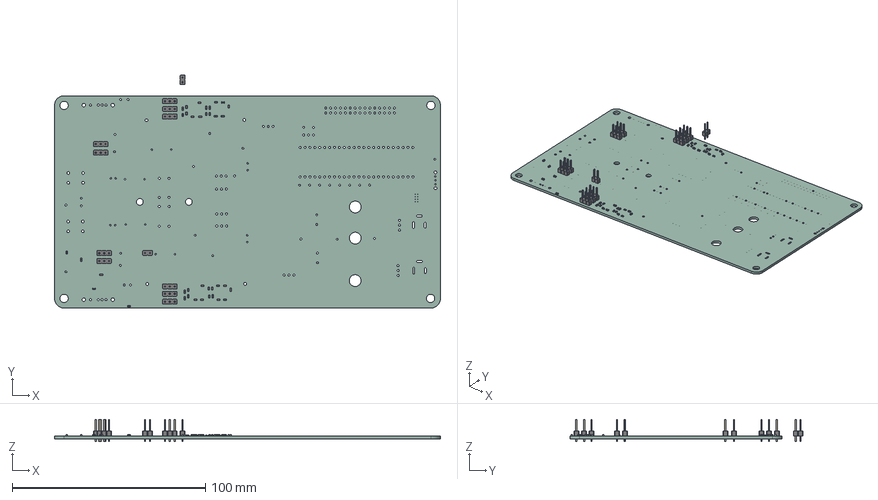
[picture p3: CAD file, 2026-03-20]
CAD/PCB_CAD/Lorentz_TDM_RevB_V2.step
200.0 x 120.8 x 11.5 mm
C_0603_1608Metric x 23
PinHeader_1x03_P2.54mm_Vertical x 10
R_0603_1608Metric x 14
PinHeader_1x02_P2.54mm_Vertical x 2
Lorentz_TDM_RevB_PCB

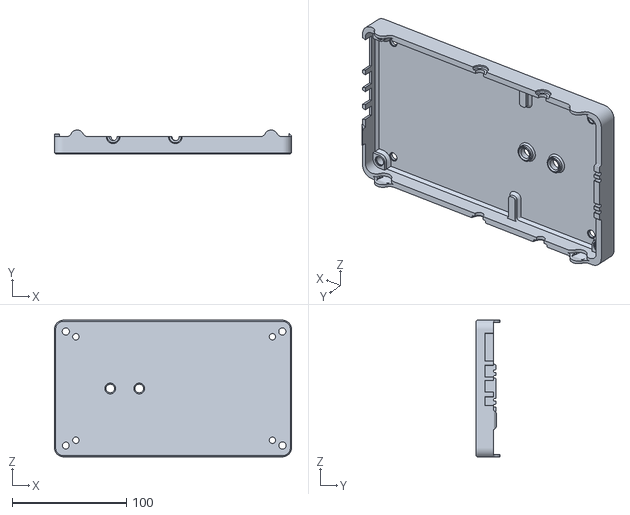
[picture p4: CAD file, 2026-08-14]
CAD/Enclosure/enclosure_base.stl
207.8 x 21.1 x 119.8

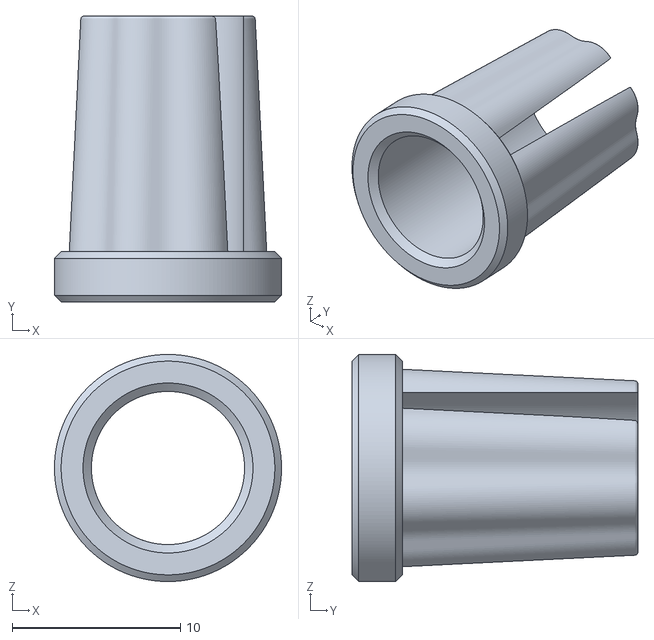
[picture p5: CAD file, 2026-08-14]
CAD/Enclosure/knob_outer.stl
13.5 x 17.0 x 13.5

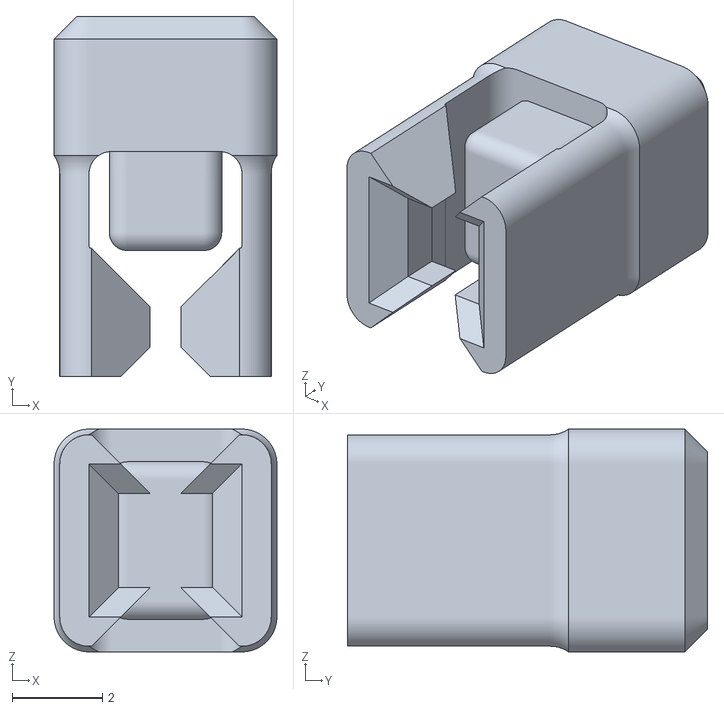
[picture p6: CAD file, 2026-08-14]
CAD/Enclosure/button_latching.stl
4.95 x 8.00 x 4.95

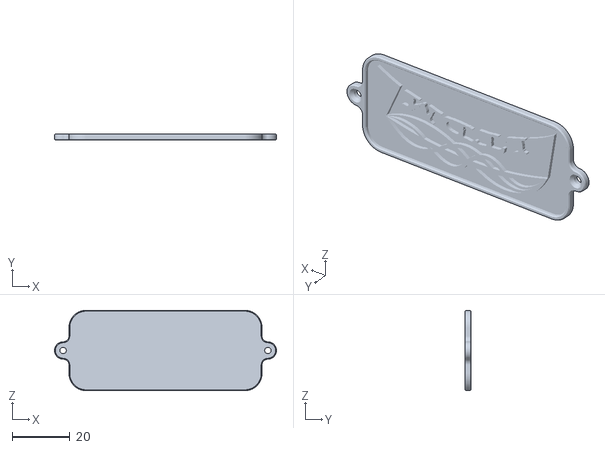
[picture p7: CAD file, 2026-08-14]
CAD/Enclosure/Logo Plate.stl
76.9 x 2.00 x 27.9

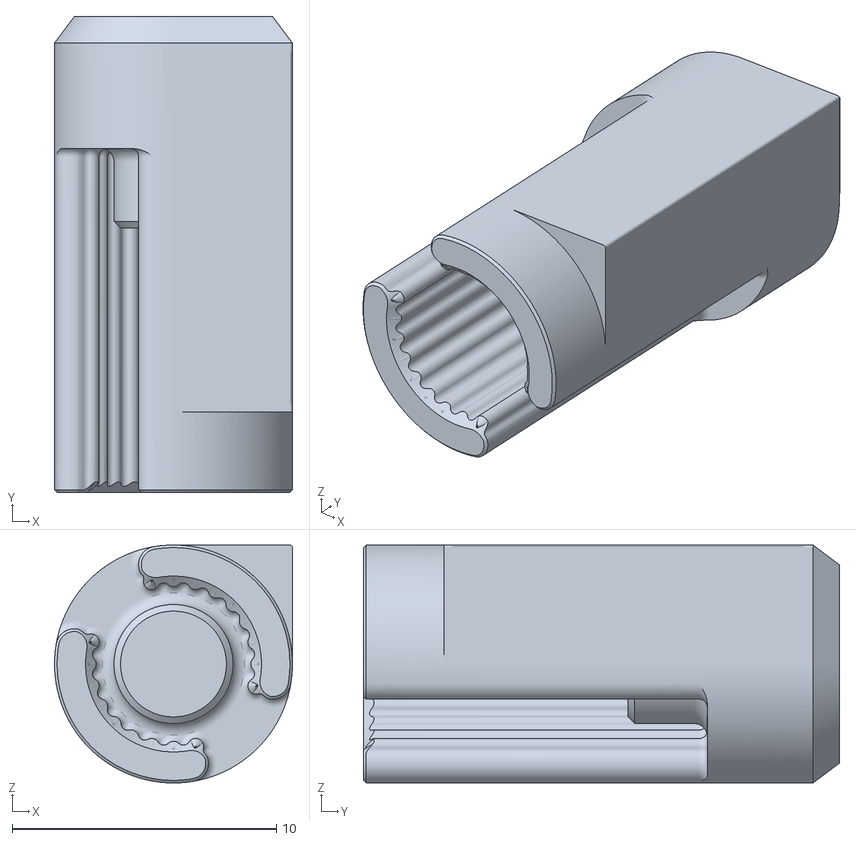
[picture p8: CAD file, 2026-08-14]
CAD/Enclosure/knob_inner.stl
9.00 x 18.0 x 9.00

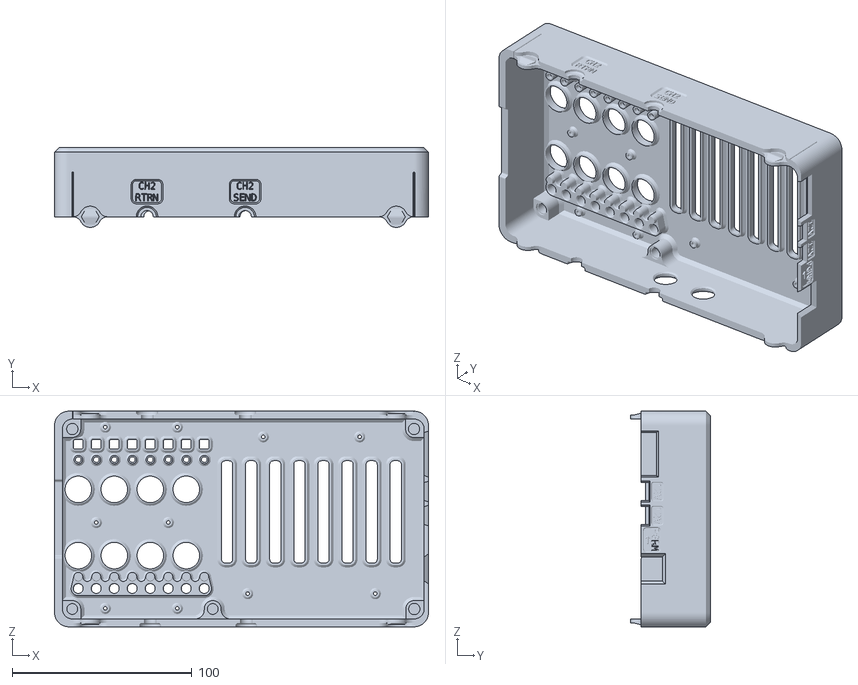
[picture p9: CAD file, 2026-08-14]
CAD/Enclosure/enclosure_top.stl
207.8 x 44.3 x 119.8

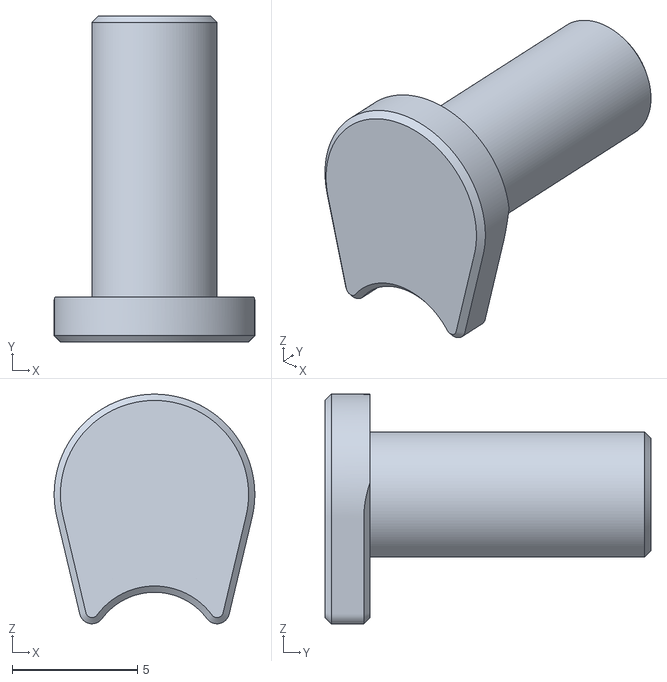
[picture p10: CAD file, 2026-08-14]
CAD/Enclosure/button_tactile.stl
8.00 x 13.0 x 9.16

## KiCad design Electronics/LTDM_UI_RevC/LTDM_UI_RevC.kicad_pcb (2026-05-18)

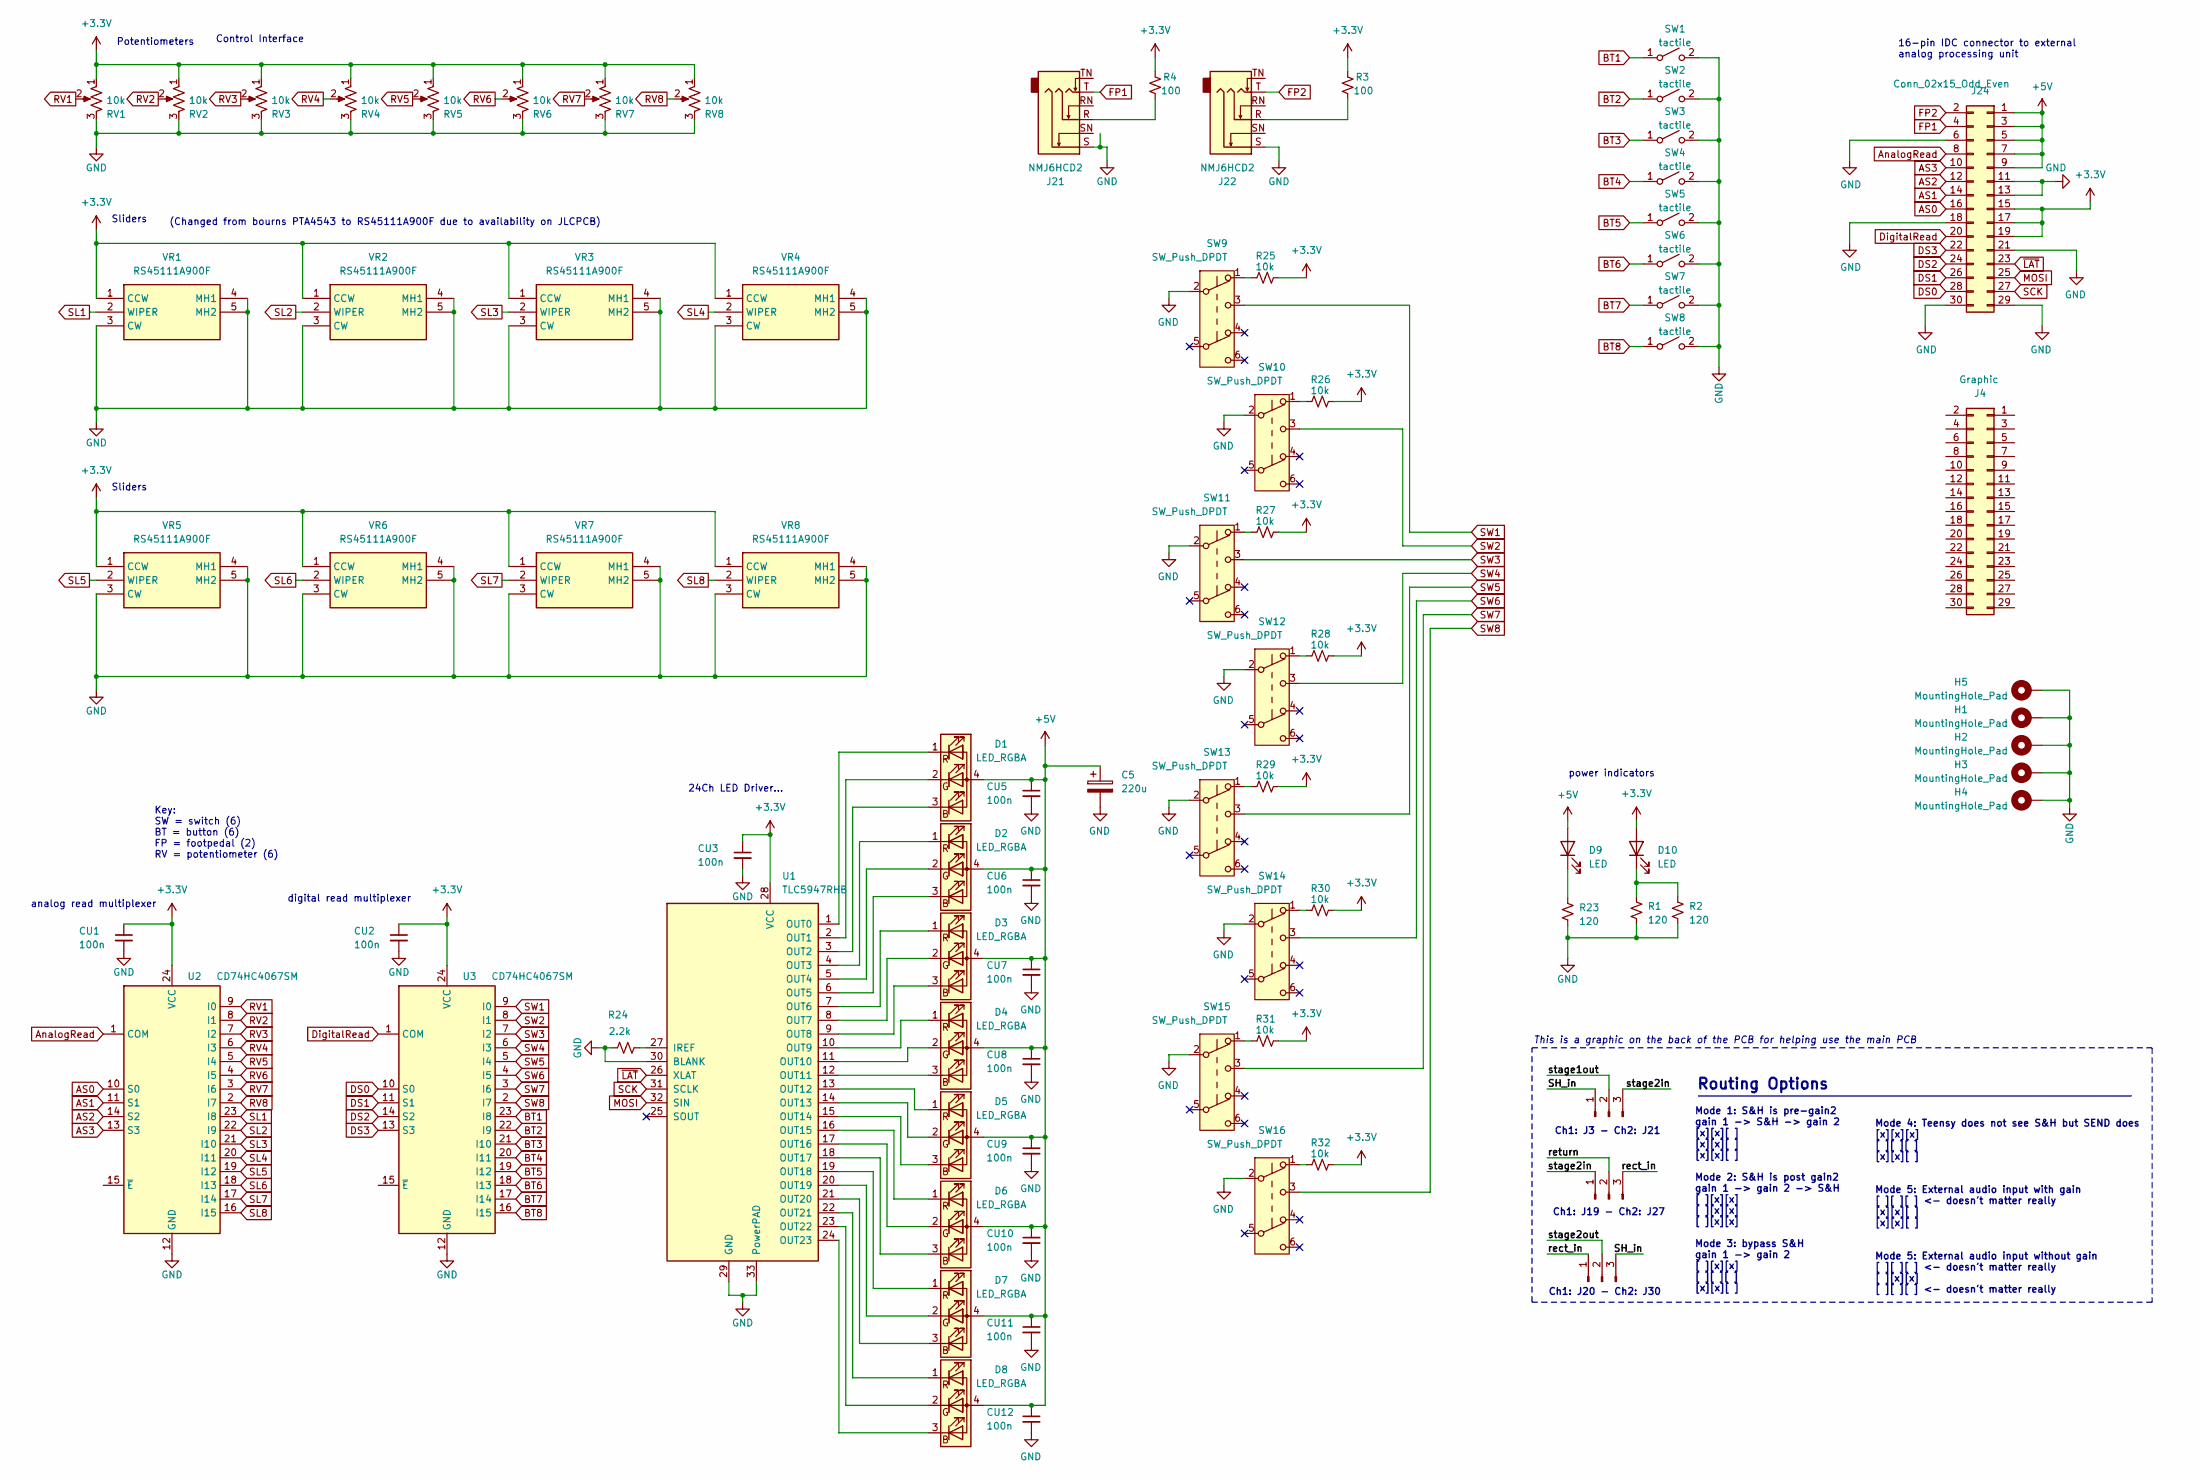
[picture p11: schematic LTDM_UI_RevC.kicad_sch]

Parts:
C5: 220u; CP_Radial_D8.0mm_P3.50mm; LCSC C45072
CU1, CU2, CU3, CU5, CU6, CU7, CU8, CU9, CU10, CU11, CU12: 100n; C_0603_1608Metric
D1, D2, D3, D4, D5, D6, D7, D8: LED_RGBA; 19237R6GHBHCA012T; LCSC C60105
D9, D10: LED; LED_0603_1608Metric; LCSC C79636
H1, H2, H3, H4, H5: MountingHole_Pad; MountingHole_4.3mm_M4_ISO14580_Pad
J1, J2, J3: Conn_01x03_Male
J4: Graphic; IDC-Header_2x15_P2.54mm_Vertical_SILKSCREEN; LCSC C358748
J21, J22: NMJ6HCD2; Jack_6.35mm_Neutrik_NMJ6HCD2_Horizontal; LCSC C368502
J24: Conn_02x15_Odd_Even; IDC-Header_2x15_P2.54mm_Vertical; LCSC C358748
R1, R2, R23: 120; R_0603_1608Metric
R3, R4: 100; R_0603_1608Metric
R24: 2.2k; R_0603_1608Metric
R25, R26, R27, R28, R29, R30, R31, R32: 10k; R_0603_1608Metric
RV1, RV2, RV3, RV4, RV5, RV6, RV7, RV8: 10k; Potentiometer_Bourns_PTV09A-1_Single_Vertical; LCSC C5357831
SW1, SW2, SW3, SW4, SW5, SW6, SW7, SW8: tactile; SW_Push_1P1T_NO_Vertical_Wuerth_434133025816; LCSC C5504987
SW9, SW10, SW11, SW12, SW13, SW14, SW15, SW16: SW_Push_DPDT; SW_Push_DPDT_PS-5850SVB-6PL; LCSC C5155567
U1: TLC5947RHB; QFN-32-1EP_5x5mm_P0.5mm_EP3.45x3.45mm; LCSC C181402
U2, U3: CD74HC4067SM; SSOP-24_5.3x8.2mm_P0.65mm; LCSC C98457
VR1, VR2, VR3, VR4, VR5, VR6, VR7, VR8: RS45111A900F; Mouser Part Number 688-RS45111A900F

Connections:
+3.3V: CU1.1, CU2.1, CU3.1, D10.2 (A), J24.15, J24.17, J24.19, R3.1, R4.1, R25.1, R26.1, R27.1, R28.1, R29.1, R30.1, R31.1, R32.1, RV1.1, RV2.1, RV3.1, RV4.1, RV5.1, RV6.1, RV7.1, RV8.1, U1.28 (VCC), U2.24 (VCC), U3.24 (VCC), VR1.1 (CCW), VR2.1 (CCW), VR3.1 (CCW), VR4.1 (CCW), VR5.1 (CCW), VR6.1 (CCW), VR7.1 (CCW), VR8.1 (CCW)
+5V: C5.1, CU5.1, CU6.1, CU7.1, CU8.1, CU9.1, CU10.1, CU11.1, CU12.1, D1.4 (A), D2.4 (A), D3.4 (A), D4.4 (A), D5.4 (A), D6.4 (A), D7.4 (A), D8.4 (A), D9.2 (A), J24.1, J24.3, J24.5, J24.7, J24.9
AS0: J24.16, U2.10 (S0)
AS1: J24.14, U2.11 (S1)
AS2: J24.12, U2.14 (S2)
AS3: J24.10, U2.13 (S3)
AnalogRead: J24.8, U2.1 (COM)
BT1: SW1.1 (A), U3.23 (I8)
BT2: SW2.1 (A), U3.22 (I9)
BT3: SW3.1 (A), U3.21 (I10)
BT4: SW4.1 (A), U3.20 (I11)
BT5: SW5.1 (A), U3.19 (I12)
BT6: SW6.1 (A), U3.18 (I13)
BT7: SW7.1 (A), U3.17 (I14)
BT8: SW8.1 (A), U3.16 (I15)
DS0: J24.28, U3.10 (S0)
DS1: J24.26, U3.11 (S1)
DS2: J24.24, U3.14 (S2)
DS3: J24.22, U3.13 (S3)
DigitalRead: J24.20, U3.1 (COM)
FP1: J21.T, J24.4
FP2: J22.T, J24.2
GND: C5.2, CU1.2, CU2.2, CU3.2, CU5.2, CU6.2, CU7.2, CU8.2, CU9.2, CU10.2, CU11.2, CU12.2, H1.1, H2.1, H3.1, H4.1, H5.1, J21.S, J22.S, J24.6, J24.11, J24.13, J24.18, J24.21, J24.29, J24.30, R1.1, R2.1, R23.1, R24.2, RV1.3, RV2.3, RV3.3, RV4.3, RV5.3, RV6.3, RV7.3, RV8.3, SW1.2 (B), SW2.2 (B), SW3.2 (B), SW4.2 (B), SW5.2 (B), SW6.2 (B), SW7.2 (B), SW8.2 (B), SW9.2 (B), SW10.2 (B), SW11.2 (B), SW12.2 (B), SW13.2 (B), SW14.2 (B), SW15.2 (B), SW16.2 (B), U1.29 (GND), U1.30 (BLANK), U1.33 (PowerPAD), U2.12 (GND), U3.12 (GND), VR1.3 (CW), VR1.4 (MH1), VR1.5 (MH2), VR2.3 (CW), VR2.4 (MH1), VR2.5 (MH2), VR3.3 (CW), VR3.4 (MH1), VR3.5 (MH2), VR4.3 (CW), VR4.4 (MH1), VR4.5 (MH2), VR5.3 (CW), VR5.4 (MH1), VR5.5 (MH2), VR6.3 (CW), VR6.4 (MH1), VR6.5 (MH2), VR7.3 (CW), VR7.4 (MH1), VR7.5 (MH2), VR8.3 (CW), VR8.4 (MH1), VR8.5 (MH2)
MOSI: J24.25, U1.32 (SIN)
unnamed: D1.3 (BK), U1.3 (OUT2)
unnamed: D1.2 (GK), U1.2 (OUT1)
unnamed: D1.1 (RK), U1.1 (OUT0)
unnamed: D2.3 (BK), U1.6 (OUT5)
unnamed: D2.2 (GK), U1.5 (OUT4)
unnamed: D2.1 (RK), U1.4 (OUT3)
unnamed: D3.3 (BK), U1.9 (OUT8)
unnamed: D3.2 (GK), U1.8 (OUT7)
unnamed: D3.1 (RK), U1.7 (OUT6)
unnamed: D4.3 (BK), U1.12 (OUT11)
unnamed: D4.2 (GK), U1.11 (OUT10)
unnamed: D4.1 (RK), U1.10 (OUT9)
unnamed: D5.3 (BK), U1.15 (OUT14)
unnamed: D5.2 (GK), U1.14 (OUT13)
unnamed: D5.1 (RK), U1.13 (OUT12)
unnamed: D6.3 (BK), U1.18 (OUT17)
unnamed: D6.2 (GK), U1.17 (OUT16)
unnamed: D6.1 (RK), U1.16 (OUT15)
unnamed: D7.3 (BK), U1.21 (OUT20)
unnamed: D7.2 (GK), U1.20 (OUT19)
unnamed: D7.1 (RK), U1.19 (OUT18)
unnamed: D8.3 (BK), U1.24 (OUT23)
unnamed: D8.2 (GK), U1.23 (OUT22)
unnamed: D8.1 (RK), U1.22 (OUT21)
unnamed: D9.1 (K), R23.2
unnamed: D10.1 (K), R1.2, R2.2
unnamed: J1.1, J3.3
unnamed: J1.3, J2.1
unnamed: J2.3, J3.1
unnamed: J21.R, R4.2
unnamed: J22.R, R3.2
unnamed: R25.2, SW9.1 (A)
unnamed: R26.2, SW10.1 (A)
unnamed: R27.2, SW11.1 (A)
unnamed: R28.2, SW12.1 (A)
unnamed: R29.2, SW13.1 (A)
unnamed: R30.2, SW14.1 (A)
unnamed: R31.2, SW15.1 (A)
unnamed: R32.2, SW16.1 (A)
unnamed: R24.1, U1.27 (IREF)
RV1: RV1.2, U2.9 (I0)
RV2: RV2.2, U2.8 (I1)
RV3: RV3.2, U2.7 (I2)
RV4: RV4.2, U2.6 (I3)
RV5: RV5.2, U2.5 (I4)
RV6: RV6.2, U2.4 (I5)
RV7: RV7.2, U2.3 (I6)
RV8: RV8.2, U2.2 (I7)
SCK: J24.27, U1.31 (SCLK)
SL1: U2.23 (I8), VR1.2 (WIPER)
SL2: U2.22 (I9), VR2.2 (WIPER)
SL3: U2.21 (I10), VR3.2 (WIPER)
SL4: U2.20 (I11), VR4.2 (WIPER)
SL5: U2.19 (I12), VR5.2 (WIPER)
SL6: U2.18 (I13), VR6.2 (WIPER)
SL7: U2.17 (I14), VR7.2 (WIPER)
SL8: U2.16 (I15), VR8.2 (WIPER)
SW1: SW9.3 (C), U3.9 (I0)
SW2: SW10.3 (C), U3.8 (I1)
SW3: SW11.3 (C), U3.7 (I2)
SW4: SW12.3 (C), U3.6 (I3)
SW5: SW13.3 (C), U3.5 (I4)
SW6: SW14.3 (C), U3.4 (I5)
SW7: SW15.3 (C), U3.3 (I6)
SW8: SW16.3 (C), U3.2 (I7)
~LAT: J24.23, U1.26 (XLAT)

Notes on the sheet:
(Changed from bourns PTA4543 to RS45111A900F due to availability on JLCPCB)
24Ch LED Driver...
Mode 4: Teensy does not see S&H but SEND does [x][x][x] [ ][ ][ ] [x][x][ ] Mode 5: External audio input with gain [ ][ ][ ] <- doesn't matter really [x][x][ ] [x][x][ ] Mode 5: External audio input without gain [ ][ ][ ] <- doesn't matter really [ ][x][x] [ ][ ][ ] <- doesn't matter really
Sliders
Control Interface
digital read multiplexer
This is a graphic on the back of the PCB for helping use the main PCB
Key: SW = switch (6) BT = button (6) FP = footpedal (2) RV = potentiometer (6)
Potentiometers
Routing Options
Mode 1: S&H is pre-gain2 gain 1 -> S&H -> gain 2 [x][x][ ] [x][x][ ] [x][x][ ] Mode 2: S&H is post gain2 gain 1 -> gain 2 -> S&H [ ][x][x] [ ][x][x] [ ][x][x] Mode 3: bypass S&H gain 1 -> gain 2 [ ][x][x] [ ][ ][ ] [x][x][ ]
Ch1: J3 - Ch2: J21
16-pin IDC connector to external analog processing unit
Ch1: J19 - Ch2: J27
power indicators
Ch1: J20 - Ch2: J30
analog read multiplexer

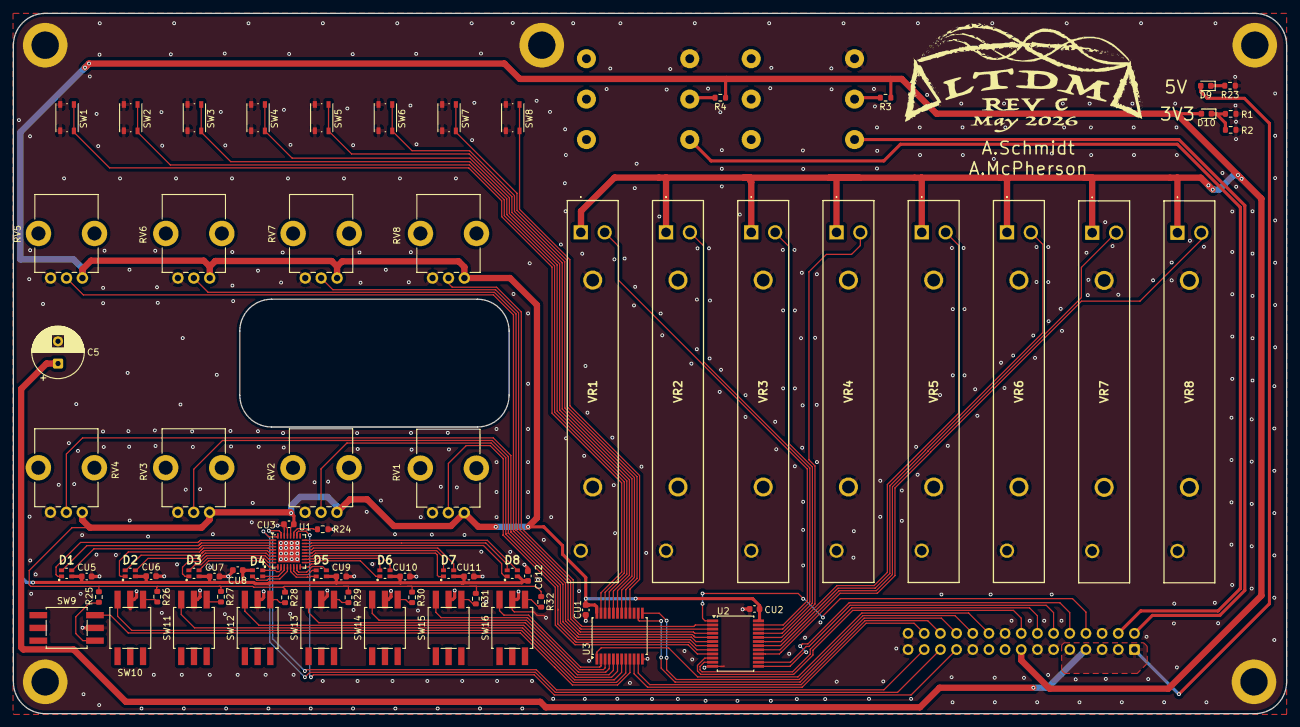
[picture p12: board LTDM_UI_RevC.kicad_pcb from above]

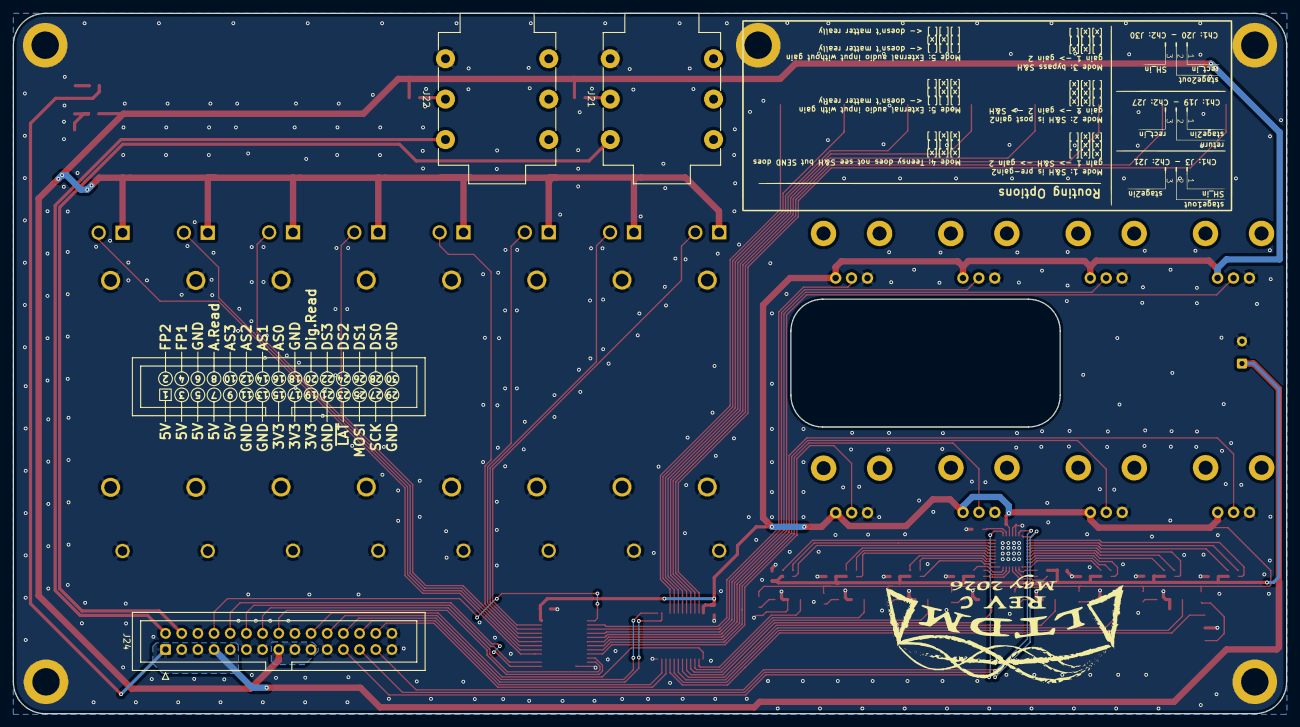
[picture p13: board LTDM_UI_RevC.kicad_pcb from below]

Board: 2 copper layers, 200.0 x 110.0 mm, 80 parts (4 on the bottom side), 87 nets.

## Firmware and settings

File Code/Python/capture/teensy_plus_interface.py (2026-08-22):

import argparse
import json
import os
import select
import subprocess
import time
from datetime import datetime, timezone
from pathlib import Path

import serial
from core.experiment_profile import ensure_experiment_profile, ensure_scope_channel_labels
from core.path_layout import build_trial_paths
from core.trial_metadata import (
    infer_trial_status,
    iso_timestamps_pair,
    normalise_controls,
    normalise_flexpwm_timing,
    relative_path,
)

CMD_ARM = b"A"
CMD_STOP = b"T"
ARM_ACK = b"ARMED"
CAPTURE_MARKER = b"\xAA\x55"
TELEMETRY_PREFIX = b"@TLM1 "

DEFAULT_DURATION_S = 5
MAX_CAPTURE_SECONDS = 120
TEENSY_SAMPLE_RATE_HZ = 20000
TEENSY_CHANNELS = 2
ARM_ACK_TIMEOUT_S = 1.0
ARM_RETRY_COUNT = 5
IFACE_DEFAULT_SAMPLE_RATE_HZ = 192000
AUDACITY_STATE_FILENAME = "audacity_timeline_state.json"
AUDACITY_IFACE_CH1_TIMELINE = "_audacity_iface_ch1_timeline.wav"
AUDACITY_IFACE_CH2_TIMELINE = "_audacity_iface_ch2_timeline.wav"
AUDACITY_TEENSY_CH1_TIMELINE = "_audacity_teensy_ch1_timeline.wav"
AUDACITY_TEENSY_CH2_TIMELINE = "_audacity_teensy_ch2_timeline.wav"
AUDACITY_RESET_PASSES_DEFAULT = 8
AUDACITY_PRE_IMPORT_DELAY_S_DEFAULT = 0.75
AUDACITY_POST_IMPORT_DELAY_S_DEFAULT = 0.75
AUDACITY_PRE_SAVE_DELAY_S_DEFAULT = 0.6
AUDACITY_POST_SAVE_DELAY_S_DEFAULT = 0.4
DEBUG_LOGGING_ENABLED = False


def write_trial_manifest(manifest_path: Path, manifest: dict) -> None:
    manifest_path.write_text(json.dumps(manifest, indent=2), encoding="utf-8")


def run_post_rigol_capture(experiment: str, trial: int) -> None:
    rigol_script = Path(__file__).resolve().parents[1] / "rigol" / "capture.py"
    if not rigol_script.exists():
        raise SystemExit(f"Rigol capture script not found: {rigol_script}")

    cmd = [
        os.sys.executable,
        "-m",
        "rigol.capture",
        "--experiment",
        experiment,
        "--trial",
        str(trial),
    ]
    print("Starting Rigol capture for the same experiment/trial...")
    completed = subprocess.run(cmd)
    if completed.returncode != 0:
        raise SystemExit(int(completed.returncode))


def update_audacity_timeline(
    *,
    args,
    orchestration_dir: Path,
    audacity_dir: Path,
    iface_channel_paths,
    ch1_wav_path: Path,
    ch2_wav_path: Path,
):
    exp_dir = orchestration_dir.parent

    def ts_utc() -> str:
        return datetime.now(timezone.utc).isoformat().replace("+00:00", "Z")

    def rel(path: Path) -> str:
        try:
            return str(path.resolve().relative_to(exp_dir.resolve()))
        except Exception:
            return str(path)

    lifecycle_events = []

    def add_event(event: str, details: dict | None = None) -> None:
        lifecycle_events.append(
            {
                "ts_utc": ts_utc(),
                "event": event,
                "details": details or {},
            }
        )

    def q(path: Path) -> str:
        return str(path.resolve()).replace("\\", "\\\\").replace('"', '\\"')

    def send_checked(audacity: "AudacityPipe", command: str, timeout_s: float = 6.0) -> str:
        response = audacity.send(command, timeout_s=timeout_s)
        response_lower = response.lower()
        if "batchcommand finished: failed" in response_lower or "error:" in response_lower:
            raise RuntimeError(f"Audacity command failed: {command}; response: {response.strip()}")
        return response

    def send_checked_any(audacity: "AudacityPipe", commands: list[str], timeout_s: float = 6.0) -> tuple[str, str]:
        last_error = ""
        for cmd in commands:
            try:
                response = send_checked(audacity, cmd, timeout_s=timeout_s)
                return cmd, response
            except Exception as exc:
                last_error = str(exc)
        joined = " | ".join(commands)
        raise RuntimeError(f"All Audacity command variants failed: {joined}; last_error={last_error}")

    audacity_timeline = {
        "enabled": bool(args.audacity_import),
        "state_path": rel(orchestration_dir / AUDACITY_STATE_FILENAME),
        "project_path": rel(orchestration_dir / f"{safe_name(args.experiment)}.aup3"),
        "records": 0,
        "latest_start_s": 0.0,
        "latest_end_s": 0.0,
        "status": "skipped",
        "lifecycle_events": lifecycle_events,
    }
    if not args.audacity_import:
        add_event("close_project", {"status": "skipped", "reason": "audacity_import_disabled"})
        return audacity_timeline

    add_event("launch_attempt", {"state_path": audacity_timeline["state_path"]})

    if not iface_channel_paths or len(iface_channel_paths) < 2:
        add_event("error", {"message": "Audacity import requires interface_capture_ch1.wav and interface_capture_ch2.wav"})
        audacity_timeline["status"] = "failed"
        audacity_timeline["error"] = "Audacity import requires interface_capture_ch1.wav and interface_capture_ch2.wav"
        return audacity_timeline

    state_path = orchestration_dir / AUDACITY_STATE_FILENAME
    try:
        if args.audacity_reset_timeline or args.trial == 1:
            state = {"next_start_s": 0.0, "records": []}
        else:
            state = load_audacity_timeline_state(state_path)

        records = []
        for rec in state.get("records", []):
            if not isinstance(rec, dict):
                continue
            try:
                _ = int(rec.get("trial", -1))
                _ = float(rec.get("start_s", 0.0))
            except Exception:
                continue
            needed = ["iface_ch1", "iface_ch2", "teensy_ch1", "teensy_ch2"]
            if not all(Path(str(rec.get(k, ""))).exists() for k in needed):
                continue
            records.append(rec)

        prior_records_count = len(records)
        duration_s = wav_duration_seconds(ch1_wav_path)
        existing = next((r for r in records if int(r.get("trial", -1)) == int(args.trial)), None)
        if existing is not None:
            start_s = float(existing.get("start_s", 0.0))
            records = [r for r in records if int(r.get("trial", -1)) != int(args.trial)]
        else:
            start_s = float(state.get("next_start_s", 0.0))

        is_new_trial = existing is None
        trial_rec = {
            "trial": int(args.trial),
            "start_s": float(start_s),
            "duration_s": float(duration_s),
            "iface_ch1": str(iface_channel_paths[0].resolve()),
            "iface_ch2": str(iface_channel_paths[1].resolve()),
            "teensy_ch1": str(ch1_wav_path.resolve()),
            "teensy_ch2": str(ch2_wav_path.resolve()),
        }
        records.append(trial_rec)
        records = sorted(records, key=lambda r: float(r.get("start_s", 0.0)))

        next_start_s = 0.0
        for rec in records:
            rec_end = float(rec.get("start_s", 0.0)) + float(rec.get("duration_s", 0.0))
            next_start_s = max(next_start_s, rec_end)

        state = {
            "next_start_s": float(next_start_s),
            "records": records,
        }
        save_audacity_timeline_state(state_path, state)

        latest_end_s = float(trial_rec["start_s"]) + float(trial_rec["duration_s"])
        audacity = AudacityPipe(
            timeout_s=float(args.audacity_timeout),
            command_spacing_s=float(args.audacity_command_spacing),
        )
        project_path = orchestration_dir / f"{safe_name(args.experiment)}.aup3"
        legacy_project_path = orchestration_dir / "audacity_project.aup3"
        audacity.open()
        add_event("launch_success", {})
        try:
            should_attempt_open = bool(args.audacity_reset_timeline) or int(args.trial) == 1
            if should_attempt_open:
                if project_path.exists():
                    used_cmd, _ = send_checked_any(
                        audacity,
                        [
                            f'OpenProject2: Filename="{q(project_path)}"',
                            f'OpenProject: Filename="{q(project_path)}"',
                        ],
                        timeout_s=10.0,
                    )
                    add_event("open_project", {"path": rel(project_path), "command": used_cmd})
                elif legacy_project_path.exists():
                    used_cmd, _ = send_checked_any(
                        audacity,
                        [
                            f'OpenProject2: Filename="{q(legacy_project_path)}"',
                            f'OpenProject: Filename="{q(legacy_project_path)}"',
                        ],
                        timeout_s=10.0,
                    )
                    add_event("open_project", {"path": rel(legacy_project_path), "command": used_cmd, "legacy": True})
                else:
                    add_event("create_project", {"path": rel(project_path), "mode": "save_on_first_write"})
            else:
                add_event("open_project", {"status": "skipped", "reason": "follow_up_trial_assume_already_open"})

            do_full_rebuild = bool(args.audacity_reset_timeline) or prior_records_count == 0 or (not is_new_trial)
            if not do_full_rebuild:
                track_count = get_audacity_track_count(audacity)
                if track_count is not None and track_count < 4:
                    do_full_rebuild = True
                    add_event(
                        "create_project",
                        {
                            "mode": "auto_rebuild_due_to_missing_tracks",
                            "track_count": track_count,
                        },
                    )
            if do_full_rebuild:
                import_records_to_audacity(
                    audacity,
                    records,
                    playhead_s=latest_end_s,
                    reset_passes=max(1, int(args.audacity_reset_passes)),
                    pre_import_delay_s=max(0.0, float(args.audacity_pre_import_delay)),
                    post_import_delay_s=max(0.0, float(args.audacity_post_import_delay)),
                )
                add_event("import_tracks", {"mode": "rebuild", "records": len(records)})
            else:
                append_record_to_audacity(
                    audacity,
                    trial_rec,
                    playhead_s=latest_end_s,
                    pre_import_delay_s=max(0.0, float(args.audacity_pre_import_delay)),
                    post_import_delay_s=max(0.0, float(args.audacity_post_import_delay)),
                )
                add_event("import_tracks", {"mode": "append", "records": 1})

            pre_save_delay_s = max(0.0, float(args.audacity_pre_save_delay))
            if pre_save_delay_s > 0.0:
                time.sleep(pre_save_delay_s)

            used_cmd, _ = send_checked_any(
                audacity,
                [
                    f'SaveProject2: Filename="{q(project_path)}"',
                    f'SaveProject: Filename="{q(project_path)}"',
                ],
                timeout_s=10.0,
            )
            add_event("save_project", {"status": "saved", "path": rel(project_path), "command": used_cmd})
            audacity_timeline["status"] = "saved"

            post_save_delay_s = max(0.0, float(args.audacity_post_save_delay))
            if post_save_delay_s > 0.0:
                time.sleep(post_save_delay_s)
        finally:
            audacity.close()
            add_event("close_project", {"status": "closed_pipe"})

        dbg(
            f"audacity_timeline=records:{len(records)},latest_start_s:{trial_rec['start_s']:.3f},"
            f"latest_end_s:{latest_end_s:.3f},next_start_s:{next_start_s:.3f}"
        )

        audacity_timeline.update(
            {
                "enabled": True,
                "state_path": str(state_path),
                "records": len(records),
                "latest_start_s": float(trial_rec["start_s"]),
                "latest_end_s": float(latest_end_s),
                "next_start_s": float(next_start_s),
                "import_mode": "per-trial-clips-4-tracks",
                "rebuild_mode": bool(do_full_rebuild),
                "trial_audacity_dir": str(audacity_dir),
            }
        )
        return audacity_timeline
    except Exception as exc:
        add_event("error", {"message": str(exc)})
        audacity_timeline["status"] = "failed"
        audacity_timeline["error"] = str(exc)
        return audacity_timeline


def parse_args():
    parser = argparse.ArgumentParser(
        description="Phase 1: capture Teensy stream and audio-interface input in one Python run."
    )
    parser.add_argument("--port", required=True, help="Serial port for Teensy")
    parser.add_argument("--output-dir", default="experiments", help="Base output directory")
    parser.add_argument("--experiment", default="TeensyCapture", help="Experiment title")
    parser.add_argument("--trial", type=int, default=1, help="Trial number")
    parser.add_argument("--duration", type=int, default=None, help="Capture duration in seconds")
    parser.add_argument("--teensy-enable", action="store_true", default=True, help="Enable Teensy serial capture")
    parser.add_argument("--teensy-disable", dest="teensy_enable", action="store_false", help="Disable Teensy serial capture")

    parser.add_argument("--iface-enable", action="store_true", default=True, help="Enable interface capture")
    parser.add_argument("--iface-disable", dest="iface_enable", action="store_false", help="Disable interface capture")
    parser.add_argument("--iface-device", default=None, help="sounddevice input device (name or index)")
    parser.add_argument("--iface-channels", type=int, default=2, help="Interface input channel count")
    parser.add_argument("--iface-sample-rate", type=int, default=IFACE_DEFAULT_SAMPLE_RATE_HZ, help="Interface sample rate")
    parser.add_argument("--iface-subtype", default="PCM_16", help="WAV subtype for interface file")
    parser.add_argument(
        "--iface-start-mode",
        choices=["marker", "arm", "arm-gated"],
        default="arm-gated",
        help=(
            "When to start interface recording: "
            "'marker' starts stream on Teensy marker, "
            "'arm' starts before arming and saves whole stream, "
            "'arm-gated' starts before arming then trims to marker->stop window."
        ),
    )
    parser.add_argument("--iface-pre-roll", type=float, default=0.15, help="Seconds to record before arming Teensy")
    parser.add_argument("--iface-post-roll", type=float, default=0.15, help="Seconds to record after Teensy capture completes")
    parser.add_argument(
        "--iface-trim-to-teensy",
        action="store_true",
        default=True,
        help="Trim interface stream after alignment to exactly match Teensy duration.",
    )
    parser.add_argument(
        "--iface-no-trim-to-teensy",
        dest="iface_trim_to_teensy",
        action="store_false",
        help="Do not trim interface stream to Teensy duration.",
    )
    parser.add_argument(
        "--iface-auto-align",
        action="store_true",
        default=True,
        help="Auto-align interface capture to Teensy CH1 using per-trial envelope correlation.",
    )
    parser.add_argument(
        "--iface-no-auto-align",
        dest="iface_auto_align",
        action="store_false",
        help="Disable in-script interface alignment.",
    )
    parser.add_argument(
        "--iface-align-channel",
        type=int,
        default=1,
        help="1-based interface channel index used as alignment reference.",
    )
    parser.add_argument(
        "--iface-align-max-offset-s",
        type=float,
        default=2.0,
        help="Max absolute lag to search during alignment, in seconds.",
    )
    parser.add_argument(
        "--iface-align-envelope-ms",
        type=float,
        default=2.0,
        help="Envelope smoothing window in milliseconds for alignment.",
    )
    parser.add_argument(
        "--iface-align-analysis-hz",
        type=int,
        default=1000,
        help="Downsampled analysis rate for correlation (higher = finer but slower).",
    )
    parser.add_argument("--iface-list-devices", action="store_true", help="List interface devices and exit")
    parser.add_argument(
        "--audacity-import",
        action="store_true",
        default=True,
        help="Import/update timeline tracks in Audacity after each trial.",
    )
    parser.add_argument(
        "--no-audacity-import",
        dest="audacity_import",
        action="store_false",
        help="Disable Audacity import automation.",
    )
    parser.add_argument(
        "--audacity-command-spacing",
        type=float,
        default=0.35,
        help="Minimum seconds between Audacity script-pipe commands.",
    )
    parser.add_argument(
        "--audacity-timeout",
        type=float,
        default=3.0,
        help="Default timeout seconds for Audacity script-pipe responses.",
    )
    parser.add_argument(
        "--audacity-reset-passes",
        type=int,
        default=AUDACITY_RESET_PASSES_DEFAULT,
        help="How many remove attempts to clear existing project tracks before import.",
    )
    parser.add_argument(
        "--audacity-pre-import-delay",
        type=float,
        default=AUDACITY_PRE_IMPORT_DELAY_S_DEFAULT,
        help="Seconds to wait after reset before importing timeline tracks.",
    )
    parser.add_argument(
        "--audacity-post-import-delay",
        type=float,
        default=AUDACITY_POST_IMPORT_DELAY_S_DEFAULT,
        help="Seconds to wait after importing timeline tracks and moving playhead.",
    )
    parser.add_argument(
        "--audacity-pre-save-delay",
        type=float,
        default=AUDACITY_PRE_SAVE_DELAY_S_DEFAULT,
        help="Extra settle time before saving Audacity project.",
    )
    parser.add_argument(
        "--audacity-post-save-delay",
        type=float,
        default=AUDACITY_POST_SAVE_DELAY_S_DEFAULT,
        help="Extra settle time after saving Audacity project before closing script pipe.",
    )
    parser.add_argument(
        "--audacity-reset-timeline",
        action="store_true",
        help="Reset Audacity timeline state for this experiment before appending this trial.",
    )
    parser.add_argument(
        "--post-rigol",
        action="store_true",
        help="Run rigol/capture.py for the same experiment/trial after audio capture files are saved.",
    )
    parser.add_argument(
        "--debug",
        action="store_true",
        help="Enable verbose [DBG] timing/alignment diagnostics in terminal output.",
    )

    return parser.parse_args()


def safe_name(value: str) -> str:
    return "".join(c if c.isalnum() or c in " _-" else "_" for c in value).strip().replace(" ", "_") or "untitled"


def write_wav(filename: Path, samples: bytes, sample_rate: int, channels: int):
    import wave

    with wave.open(str(filename), "wb") as wf:
        wf.setnchannels(channels)
        wf.setsampwidth(2)
        wf.setframerate(sample_rate)
        wf.writeframes(samples)


def wav_duration_seconds(path: Path) -> float:
    import wave

    with wave.open(str(path), "rb") as wf:
        return wf.getnframes() / wf.getframerate()


def write_silence_wav(path: Path, duration_s: float, sample_rate: int) -> None:
    import wave

    total_frames = max(0, int(round(max(0.0, float(duration_s)) * float(sample_rate))))
    with wave.open(str(path), "wb") as wf:
        wf.setnchannels(1)
        wf.setsampwidth(2)
        wf.setframerate(sample_rate)
        wf.writeframes(b"\x00\x00" * total_frames)


def extract_channels(buffer: bytes, channels: int = 2):
    from array import array

    samples = array("h")
    samples.frombytes(buffer)
    if len(samples) % channels != 0:
        raise ValueError(f"Binary capture length not divisible by {channels}: {len(samples)}")

    channel_bytes = []
    for ch in range(channels):
        channel_data = array("h", samples[ch::channels])
        channel_bytes.append(channel_data.tobytes())
    return channel_bytes


def read_until_marker(ser, marker: bytes, timeout: float | None):
    deadline = None if timeout is None else time.time() + timeout
    buffer = bytearray()
    while deadline is None or time.time() < deadline:
        chunk = ser.read(ser.in_waiting or 1)
        if not chunk:
            continue
        buffer.extend(chunk)
        index = buffer.find(marker)
        if index != -1:
            return True, buffer[index + len(marker):]
        if len(buffer) > len(marker) * 8:
            buffer = buffer[-len(marker) * 8 :]
    return False, b""


def _collect_telemetry_lines_in_place(buffer: bytearray, telemetry_frames: list[dict]) -> None:
    while True:
        newline_index = buffer.find(b"\n")
        if newline_index == -1:
            return
        raw_line = bytes(buffer[:newline_index]).rstrip(b"\r")
        del buffer[: newline_index + 1]
        stripped = raw_line.strip()
        if not stripped.startswith(TELEMETRY_PREFIX):
            continue
        payload_bytes = stripped[len(TELEMETRY_PREFIX) :]
        try:
            payload_text = payload_bytes.decode("utf-8")
            payload = json.loads(payload_text)
        except Exception:
            continue
        if isinstance(payload, dict):
            telemetry_frames.append(payload)
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

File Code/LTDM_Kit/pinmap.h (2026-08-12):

// pinmap.h
#ifndef PINMAP_H
#define PINMAP_H

// OUTPUTS //
// FLEX PWM definitions
constexpr int SENSE_ALT     = 4; // FlexPWM 2.0A - alternate sense pulse (in case of small timing adjustments for S&H)
constexpr int SENSE_PULSE   = 5; // FlexPWM 2.1A - primary sense pulse (triggers ISR, traditionally triggers S&H)
constexpr int CH1_PACTUATE  = 6; // FlexPWM 2.2A (Val2+3) - Channel 1 Actuate PMOS Positive Pulse
constexpr int CH1_NACTUATE  = 9; // FlexPWM 2.2B (Val4+5) - Channel 1 Actuate NMOS Negative Pulse
constexpr int CH2_PACTUATE  = 36; //FlexPWM 2.3A (Val2+3) - Channel 2 Actuate PMOS Positive Pulse
constexpr int CH2_NACTUATE  = 37; //FlexPWM 2.3B (Val4+5) - Channel 2 Actuate NMOS Negative Pulse
constexpr int LED_PULSE     = 33; //FlexPWM 2.0B (Val4+5) - An LED pin that I have yet to figure out exactly what to do with

constexpr int CH1_ENABLE    = 24; // must be high to permit Channel 1 to be on
constexpr int CH2_ENABLE    = 25; // must be high to permit Channel 2 to be on

constexpr int CH1_ADC_PIN       = 14; // (A0) for rectified analog input
constexpr int CH1_POLARITY_PIN  = 34; // for assessing polarity of signal (Postive or Negative)
constexpr int CH1_CURRSENSE_PIN = 27; // (A13) rectified current measurement input.

constexpr int CH2_ADC_PIN       = 15; // (A1?) for rectified analog input
constexpr int CH2_POLARITY_PIN  = 35; // for assessing polarity of signal (Postive or Negative)
constexpr int CH2_CURRSENSE_PIN = 26; // (A12) rectified current measurement input

constexpr int GPIO_PIN = 7; // a random pin for debugging and benchmarking
constexpr int SERVO_PIN = 28; // pin for attaching servo

// INPUTS //
// UI multiplexers for buttons, sliders, and pots
// Buttons
constexpr int DSIN  = 2;
constexpr int DS0   = 32;
constexpr int DS1   = 31;
constexpr int DS2   = 30;
constexpr int DS3   = 3;

// Sliders & Pots
constexpr int ASIN  = 16;
constexpr int AS0   = 38;
constexpr int AS1   = 39;
constexpr int AS2   = 40;
constexpr int AS3   = 41;

// Footpedal inputs
constexpr int FP0  = 22;
constexpr int FP1  = 23;

// TLC5947 LED Driver
constexpr int tlc_data   = 11;
constexpr int tlc_clock  = 13;
constexpr int tlc_latch  = 8;

#endif // PINMAP_H

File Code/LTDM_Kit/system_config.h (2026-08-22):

// system_config.h
#ifndef SYSTEM_CONFIG_H
#define SYSTEM_CONFIG_H

// #define DEBUG // comment out to turn debug mode off
constexpr int SAMPLERATE = 20000; // Sample Rate of TDM
constexpr int ResolutionPWM = 12; // Resolution of PWM timers
constexpr int bufferLength = 2000; // Buffer size (for RMS, zero-crossing frequency meas, etc.)
constexpr float MaxDutyCh1 = 0.35; // Max duty cycle for channel 1 actuation (0.0 to 1.0)
constexpr float MaxDutyCh2 = 1.00; // Max duty cycle for channel 2 actuation (0.0 to 1.0)

#endif

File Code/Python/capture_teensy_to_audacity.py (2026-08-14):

import argparse
import json
import os
import select
import serial
import shutil
import time
import wave
from pathlib import Path
from datetime import datetime

CMD_ARM = b"A"
CMD_STOP = b"T"
ARM_ACK = b"ARMED"
CAPTURE_MARKER = b"\xAA\x55"

DEFAULT_DURATION_S = 5
SAMPLE_RATE_HZ = 20000
CHANNELS = 2
ARM_ACK_TIMEOUT_S = 1.0
ARM_RETRY_COUNT = 5
AUDACITY_POST_STOP_DELAY_S = 0.35
AUDACITY_IMPORT_SPACING_S = 0.25
AUDACITY_POST_IMPORT_DELAY_S = 0.5
AUDACITY_COMMAND_SPACING_S = 0.35
AUDACITY_PRE_CLOSE_DELAY_S = 0.75
AUDACITY_PRE_IMPORT_DELAY_S = 1.0
AUDACITY_POST_STOP_QUERY_TIMEOUT_S = 0.6
AUDACITY_STOP_RETRIES = 3
AUDACITY_STOP_EXTRA_S = 0.0
INITIAL_IMPORT_OFFSET_S = 0.0
IMPORT_STATE_FILENAME = "teensy_import_segments.json"
IMPORT_BUFFER_FILENAME = "_teensy_import_buffer.wav"
IMPORT_SEGMENTS_DIRNAME = "_teensy_segments_ch1"
IMPORT_TRACK_INDEX = 2
IMPORT_TRACK_CLEANUP_PASSES = 12


class AudacityPipe:
    def __init__(self, timeout_s: float = 2.0, command_spacing_s: float = AUDACITY_COMMAND_SPACING_S):
        uid = os.getuid()
        self.to_path = Path(f"/tmp/audacity_script_pipe.to.{uid}")
        self.from_path = Path(f"/tmp/audacity_script_pipe.from.{uid}")
        self.timeout_s = timeout_s
        self.command_spacing_s = max(0.0, float(command_spacing_s))
        self.to_pipe = None
        self.from_pipe = None
        self._last_send_time = 0.0

    def open(self):
        if not self.to_path.exists() or not self.from_path.exists():
            raise RuntimeError(
                "Audacity mod-script-pipe not available. Open Audacity and enable mod-script-pipe."
            )
        self.to_pipe = self.to_path.open("w", encoding="utf-8", buffering=1)
        self.from_pipe = self.from_path.open("r", encoding="utf-8", buffering=1)

    def close(self):
        if self.to_pipe:
            self.to_pipe.close()
            self.to_pipe = None
        if self.from_pipe:
            self.from_pipe.close()
            self.from_pipe = None

    def send(self, command: str, timeout_s: float | None = None) -> str:
        if self.to_pipe is None or self.from_pipe is None:
            raise RuntimeError("Audacity pipe is not open")

        now = time.time()
        elapsed = now - self._last_send_time
        if self.command_spacing_s > 0.0 and elapsed < self.command_spacing_s:
            time.sleep(self.command_spacing_s - elapsed)

        self.to_pipe.write(command + "\n")
        self.to_pipe.flush()
        self._last_send_time = time.time()

        fd = self.from_pipe.fileno()
        response_lines = []
        timeout = self.timeout_s if timeout_s is None else timeout_s
        deadline = time.time() + timeout

        while time.time() < deadline:
            remaining = max(0.0, deadline - time.time())
            readable, _, _ = select.select([fd], [], [], remaining)
            if not readable:
                continue
            line = self.from_pipe.readline()
            if line == "":
                break
            response_lines.append(line)
            if line.strip() == "":
                break

        return "".join(response_lines)


def parse_args():
    parser = argparse.ArgumentParser(
        description="Arm Teensy capture, start/stop Audacity recording on button press, and import captured WAV."
    )
    parser.add_argument("--port", required=True, help="Serial port for Teensy")
    parser.add_argument("--output-dir", default="experiments", help="Base output directory")
    parser.add_argument("--experiment", default="TeensyCapture", help="Experiment title")
    parser.add_argument("--trial", type=int, default=1, help="Trial number")
    parser.add_argument("--duration", type=int, default=None, help="Capture duration in seconds")
    parser.add_argument(
        "--record-command",
        default="Record1stChoice",
        help="Audacity recording command (e.g., Record1stChoice or Record2ndChoice)",
    )
    parser.add_argument(
        "--skip-audacity",
        action="store_true",
        help="Skip Audacity control (for serial-capture-only testing)",
    )
    parser.add_argument(
        "--audacity-mode",
        choices=["record-stop-import-ch1", "record-stop", "import-ch1-only"],
        default="record-stop-import-ch1",
        help="Choose which Audacity actions to run for crash isolation.",
    )
    parser.add_argument(
        "--post-stop-delay",
        type=float,
        default=AUDACITY_POST_STOP_DELAY_S,
        help="Seconds to wait after Stop before any import command.",
    )
    parser.add_argument(
        "--audacity-stop-extra-s",
        type=float,
        default=AUDACITY_STOP_EXTRA_S,
        help="Extra seconds to keep Audacity recording after Teensy capture completes.",
    )
    parser.add_argument(
        "--import-spacing",
        type=float,
        default=AUDACITY_IMPORT_SPACING_S,
        help="Seconds to wait between Audacity import-related commands.",
    )
    parser.add_argument(
        "--reopen-pipe-before-import",
        action="store_true",
        default=False,
        help="Reopen mod-script-pipe before import when combining record/stop+import.",
    )
    parser.add_argument(
        "--no-reopen-pipe-before-import",
        dest="reopen_pipe_before_import",
        action="store_false",
        help="Do not reopen mod-script-pipe before import.",
    )
    parser.add_argument(
        "--post-import-delay",
        type=float,
        default=AUDACITY_POST_IMPORT_DELAY_S,
        help="Seconds to wait after import before exiting the script.",
    )
    parser.add_argument(
        "--audacity-command-spacing",
        type=float,
        default=AUDACITY_COMMAND_SPACING_S,
        help="Minimum seconds between any two Audacity pipe commands.",
    )
    parser.add_argument(
        "--pre-close-delay",
        type=float,
        default=AUDACITY_PRE_CLOSE_DELAY_S,
        help="Seconds to wait before closing the Audacity pipe at shutdown.",
    )
    parser.add_argument(
        "--pre-import-delay",
        type=float,
        default=AUDACITY_PRE_IMPORT_DELAY_S,
        help="Seconds to wait just before sending Import2.",
    )
    parser.add_argument(
        "--initial-import-offset-s",
        type=float,
        default=INITIAL_IMPORT_OFFSET_S,
        help="Applied only when the first segment anchor is 0.0 (playhead metadata unavailable).",
    )
    parser.add_argument(
        "--skip-track-removal",
        action="store_true",
        default=False,
        help="Do not issue track removal commands (safer for Audacity stability).",
    )
    parser.add_argument(
        "--allow-track-removal",
        dest="skip_track_removal",
        action="store_false",
        help="Allow track removal commands before re-import.",
    )
    parser.add_argument(
        "--leave-audacity-pipe-open",
        action="store_true",
        default=True,
        help="Skip explicit pipe close at shutdown (lets Audacity settle on process exit).",
    )
    parser.add_argument(
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

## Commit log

2026-03-24 Improved and characterized ADC sample time
    Previously took ~6.3uS to sample both ADCs but have gotten it down to a sweet ~3.4uS by disabling 'long sampling mode' and ADC_CFG_ADSTS(3) to ADC_CFG_ADSTS(0). Apparently that was upping sample time.
    This arrangement is likely noisier but gives a user an extra 3.5uS to play with in render()
    This is for 600MHz.
    Trimming away old code too :)
    [LTDM_RevC.kicad_sch, String_Drivers_GD.kicad_sch]
2026-03-25 Reinstated RMS + noise (and now a rudimentary lowpass on noise!)
    This is the code brought to the Marco Fusi session!
    RMS limiting now actually actively damps when the RMS is measured too high. Neat!
    [flexpwm.cpp, system_config.h, ui.cpp]
2026-04-13 Channel 2 fixed!
    Channel 2 now working again
    Now you can enable/disable RMS limiting and noise
    LEDs indicate settings (refer to visualguide.jpg)
    [LTDM_RevC.kicad_sch]
2026-05-18 Boards Ordered!
    The KiCad files are the ones that were ordered
    [CurrentSense.kicad_sch, LTDM_RevC.kicad_sch, LTDM_UI_RevC.kicad_pcb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]
2026-06-21 About to start messing with Serial connectivity to max/msp
    [LTDM_UI_RevC.kicad_sch]
2026-07-21 Fixed bug in serial communication
    now successfully connects to LTDM kit from max patch
    [LTDM_Kit.ino, flexpwm.cpp, flexpwm.h]
2026-07-21 Harmonic Re-synthesis
    The code now actively listens to the input signal. Using zero-cross detection, we estimate the frequency of the vibrating subject. Harmonics are calculated and then applied to the strings with a gain corresponding to the fader positions.
    Sometimes a string vibrates in a way that crosses zero multiple times, creating little glitchy things that can actually be quite cool. Sometimes it's just annoying noise though.
    Only on channel 1 for now.
    [LTDM_Kit.ino]
2026-08-12 Stroboscopic stuff, characterization stuff...
    [CurrentSense.kicad_sch, LTDM_RevC.kicad_sch, Preamp+Rectifier.kicad_sch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]
2026-08-14 CAD for enclosure + UI organized and added
    [Logo Plate.stl, Lorentz_TDM_RevB_V2.step, button_latching.stl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]
2026-08-14 Update readme. Remove servo capabilities.
2026-08-21 - Revised file structure for data collection - Update Python README - fixed issue where rigol_capture.py hangs if rigol scope is not connected (and now exits and prompts user to connect if not alread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
    [capture_teensy_plus_interface.py, capture_teensy_stream.py, load_rigol_capture.py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]
2026-08-28 Now toggle harmonic synthesis with Button 4 Report firmware config variables to metadata
2026-09-04 Minor comments, experimental sample rate
